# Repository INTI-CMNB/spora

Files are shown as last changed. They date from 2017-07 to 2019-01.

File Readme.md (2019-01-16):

SPORA PRE-RELEASE
==================

BUILD AWESOME WEARABLES

Open hardware platform for wearables.

Lots of sensors ready to use, program and expand at ease. All packed in an incredible small size.
More info at [Spora web page](https://sporaio.com/).

Final release in [Spora repo](https://github.com/sporaio).

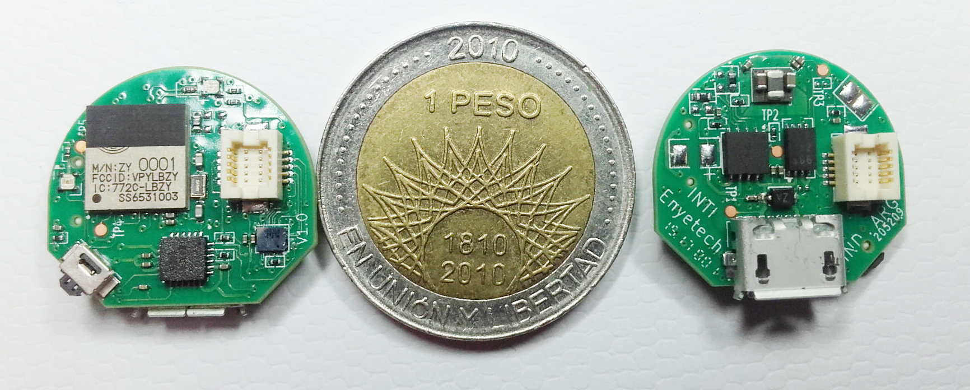
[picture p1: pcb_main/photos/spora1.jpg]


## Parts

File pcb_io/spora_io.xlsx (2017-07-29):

 |  |  |  |  |  |  | Board Qty: | 10
 |  |  |  |  |  |  | Total Cost: | $19.35 |  |  |  | $34.15 |  |  |  |  |  | $23.18 |  |  |  |  |  | $21.41 |  |  |  |  |  | $20.79 |  |  |  |  |  | $264.58
 |  |  |  |  |  |  | Unit Cost: | $1.93
Global Part Info |  |  |  |  |  |  |  |  | Digi-Key |  |  |  |  |  | Farnell |  |  |  |  |  | Mouser |  |  |  |  |  | Newark |  |  |  |  |  | Rs Components
Refs | Value | Desc | Footprint | Manf | Manf# | Qty | Unit$ | Ext$ | Avail | Purch | Unit$ | Ext$ | Cat# | Doc | Avail | Purch | Unit$ | Ext$ | Cat# | Doc | Avail | Purch | Unit$ | Ext$ | Cat# | Doc | Avail | Purch | Unit$ | Ext$ | Cat# | Doc | Avail | Purch | Unit$ | Ext$ | Cat# | Doc
J1 | DF12B 3.0 10DS 0.5V 81 | 10 Position Connector Receptacle, Center Strip Contacts Surface Mount Gold | footprints:df12(3.0)-10ds-0.5v | Hirose Electric Co Ltd | DF12B 3.0 -10DS- 0.5V 86 | 10 | $0.62 | $6.19 |  |  | $0.77 | $7.74 | H11719CT-ND | Link (http://www.digikey.com/scripts/DkSearch/dksus.dll?WT.z_header=search_go&lang=en) |  |  |  |  |  |  | 155 |  | $0.62 | $6.19 | 798-DF12B3010DS05V86 | Link (http://www.mouser.com/Search/Refine.aspx?Keyword=DF12B%203.0%20-10DS-%200.5V%2086%20)
C1,C2,C5-C8 | 1uF | CAP CER 1UF 16V X5R 0402 | footprints:c_0402 | Taiyo Yuden | EMK105BJ105KV-F | 60 | $0.03 | $1.75 | 602469 |  | $0.06 | $3.66 | 587-2477-1-ND | Link (http://www.digikey.com/scripts/DkSearch/dksus.dll?WT.z_header=search_go&lang=en) | 9184 |  | $0.03 | $1.75 | 2113064 | Link (http://it.farnell.com/taiyo-yuden/emk105bj105kv-f/condensatore-mlcc-x5r-1uf-16v/dp/2113064) | 58536 |  | $0.06 | $3.60 | 963-EMK105BJ105KV-F | Link (http://www.mouser.com/Search/Refine.aspx?Keyword=EMK105BJ105KV-F%20%20) |  |  | $0.19 | $11.40 | 84R9108 | Link (http://www.newark.com/taiyo-yuden/emk105bj105kv-f/ceramic-capacitor-1uf-16v-x5r/dp/84R9108)
G1 | LOGO_INTI | Logo INTI | footprints:LOGO_INTI |  |  | 10 | $0.00 | $0.00
CON2 | CON2 | Pad coneccion para tension de alimentacion del display | footprints:GS2 |  |  | 10 | $0.00 | $0.00
CON1 | CON6 | Conector para las lineas de SPI | footprints:CON_SPI_SMD |  |  | 10 | $0.00 | $0.00
J2 | ER-OLED0.49-1Series | Display OLED 0.49 | footprints:ER-OLED0.49-1_B |  |  | 10 | $0.00 | $0.00
C4 | 4.7uF | CAP CER 4.7UF 10V X5R 0402 | footprints:c_0402 | Samsung Electro-Mechanics America, Inc. | CL05A475MP5NRNC | 10 | $0.21 | $2.14 | 580535 |  | $0.21 | $2.14 | 1276-1482-1-ND | Link (http://www.digikey.com/scripts/DkSearch/dksus.dll?WT.z_header=search_go&lang=en) |  |  |  |  |  |  |  |  |  |  | Not Assigned | Link (http://www.mouser.com/Search/Refine.aspx?Keyword=CL05A475MP5NRNC%20)
C3 | 2.2uF | CAP CER 2.2UF 10V X5R 0402 | footprints:c_0402 | Murata Electronics North America | GRM155R61A225KE95D | 10 | $0.02 | $0.21 | 515443 |  | $0.07 | $0.66 | 490-10451-1-ND | Link (http://www.digikey.com/scripts/DkSearch/dksus.dll?WT.z_header=search_go&lang=en) | 18288 |  | $0.03 | $0.31 | 2456102 | Link (http://it.farnell.com/murata/grm155r61a225ke95d/condensatore-mlcc-x5r-2-2uf-10v/dp/2456102) | 263995 |  | $0.06 | $0.60 | 81-GRM155R61A225KE5D | Link (http://www.mouser.com/ProductDetail/Murata-Electronics/GRM155R61A225KE95D/) | 40000 |  | $0.02 | $0.21 | 03AC2565 | Link (http://www.newark.com/murata/grm155r61a225ke95d/capacitor-mlcc-x5r-2-2uf-10v-0402/dp/03AC2565)
R1 | 390K | RES SMD 390K OHM 1/16W 0402 | footprints:r_0402 | Yageo | RC0402JR-07390KL | 10 | $0.002 | $0.02 | 98703 |  | $0.01 | $0.12 | 311-390KJRCT-ND | Link (http://www.digikey.com/scripts/DkSearch/dksus.dll?WT.z_header=search_go&lang=en) |  |  |  |  | 9233075 | Link (http://it.farnell.com/webapp/wcs/stores/servlet/Search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) | 18070 |  | $0.01 | $0.08 | 603-RC0402JR-07390KL | Link (http://www.mouser.com/Search/Refine.aspx?Keyword=RC0402JR-07390KL%20%20Yageo) |  |  | $0.002 | $0.02 | 68R0007 | Link (http://www.newark.com/webapp/wcs/stores/servlet/Search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)
R5-R8 | 0 ohm | RES SMD 0.0OHM JUMPER 1/16W 0402 | footprints:r_0402 | Yageo | RC0402JR-070RL | 40 | $0.01 | $0.27 | 12655472 |  | $0.01 | $0.27 | 311-0.0JRCT-ND | Link (http://www.digikey.com/scripts/DkSearch/dksus.dll?WT.z_header=search_go&lang=en) | 185914 |  | $0.01 | $0.28 | 9232516 | Link (http://it.farnell.com/yageo-phycomp/rc0402jr-070rl/res-film-spesso-0r-5-0-0625w-0402/dp/9232516) | 1644687 |  | $0.01 | $0.32 | 603-RC0402JR-070RL | Link (http://www.mouser.com/Search/Refine.aspx?Keyword=RC0402JR-070RL%20Yageo) | 10896 |  | $0.01 | $0.28 | 67R9963 | Link (http://www.newark.com/yageo/rc0402jr-070rl/res-thick-film-0r-0-0625w-0402/dp/67R9963) | 2 |  | $4.71 | $188.36 | 618-5804 | Link (http://it.rs-online.com/web/c/?searchTerm=RC0402JR-070RL%20Yageo)
R4 | 0 ohm | RES SMD 0.0OHM JUMPER 1/16W 0402 | footprints:r_0402 | Yageo | RC0402JR-070RL | 10 | $0.01 | $0.07 | 12655472 |  | $0.01 | $0.10 | 311-0.0JRCT-ND | Link (http://www.digikey.com/scripts/DkSearch/dksus.dll?WT.z_header=search_go&lang=en) | 185914 |  | $0.01 | $0.07 | 9232516 | Link (http://it.farnell.com/yageo-phycomp/rc0402jr-070rl/res-film-spesso-0r-5-0-0625w-0402/dp/9232516) | 1644687 |  | $0.01 | $0.08 | 603-RC0402JR-070RL | Link (http://www.mouser.com/Search/Refine.aspx?Keyword=RC0402JR-070RL%20%20Yageo) | 10896 |  | $0.01 | $0.10 | 67R9963 | Link (http://www.newark.com/yageo/rc0402jr-070rl/res-thick-film-0r-0-0625w-0402/dp/67R9963) | 2 |  | $4.71 | $47.09 | 618-5804 | Link (http://it.rs-online.com/web/c/?searchTerm=RC0402JR-070RL%20%20Yageo)
R2,R3 | 10K | RES SMD 10K OHM 1/16W 0402 | footprints:r_0402 | Yageo | RC0402JR-0710KL | 20 | $0.01 | $0.11 | 3732168 |  | $0.01 | $0.24 | 311-10KJRCT-ND | Link (http://www.digikey.com/scripts/DkSearch/dksus.dll?WT.z_header=search_go&lang=en) | 112344 |  | $0.01 | $0.11 | 9232885 | Link (http://it.farnell.com/yageo-phycomp/rc0402jr-0710kl/res-film-spesso-10k-5-0-0625w/dp/9232885) | 307085 |  | $0.01 | $0.16 | 603-RC0402JR-0710KL | Link (http://www.mouser.com/Search/Refine.aspx?Keyword=RC0402JR-0710KL%20Yageo) | 44886 |  | $0.01 | $0.20 | 67R9964 | Link (http://www.newark.com/yageo/rc0402jr-0710kl/res-thick-film-10k-5-0-0625w-0402/dp/67R9964)
SW1,SW2 | SW_PUSH | SWITCH TACTILE SPST-NO 0.05A 12V | footprints:B3U_3000PB | Omron Electronics Inc-EMC Div | B3U-3000P-B | 20 | $0.43 | $8.58 | 17298 |  | $0.96 | $19.22 | SW1256CT-ND | Link (http://www.digikey.com/product-detail/en/omron-electronics-inc-emc-div/B3U-3000P-B/SW1256CT-ND/2748498) | 2004 |  | $1.03 | $20.66 | 1333656 | Link (http://it.farnell.com/omron-electronic-components/b3u-3000p-b/tactile-switch-side-actuated-smd/dp/1333656) | 557 |  | $0.52 | $10.38 | 653-B3U-3000P-B | Link (http://www.mouser.com/Search/Refine.aspx?Keyword=B3U-3000P-B%20%20) | 4000 |  | $0.43 | $8.58 | 39M4624 | Link (http://www.newark.com/omron-electronic-components/b3u-3000p-b/switch-tactile-spst-no-50ma-smd/dp/39M4624) |  |  | $1.46 | $29.13 | 807-4321 | Link (http://it.rs-online.com/web/c/?searchTerm=B3U-3000P-B%20%20)

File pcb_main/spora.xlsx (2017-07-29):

 |  |  |  |  |  |  | Board Qty: | 100
 |  |  |  |  |  |  | Total Cost: | $0.00 |  |  |  | $0.00 |  |  |  |  |  | $0.00 |  |  |  |  |  | $0.00 |  |  |  |  |  | $0.00 |  |  |  |  |  | $0.00
 |  |  |  |  |  |  | Unit Cost: | $0.00
Global Part Info |  |  |  |  |  |  |  |  | Digi-Key |  |  |  |  |  | Farnell |  |  |  |  |  | Mouser |  |  |  |  |  | Newark |  |  |  |  |  | Rs Components
Refs | Value | Desc | Footprint | Manf | Manf# | Qty | Unit$ | Ext$ | Avail | Purch | Unit$ | Ext$ | Cat# | Doc | Avail | Purch | Unit$ | Ext$ | Cat# | Doc | Avail | Purch | Unit$ | Ext$ | Cat# | Doc | Avail | Purch | Unit$ | Ext$ | Cat# | Doc | Avail | Purch | Unit$ | Ext$ | Cat# | Doc
G2 | LOGO_INTI |  |  |  |  | 0 | $0.00 | $0.00
U1 | TPS2115a | IC OR CTRLR SRC SELECT 8SON | footprints:TPS2115A | Texas Instruments | TPS2115ADRBR | 0 | $0.00 | $0.00 | 15291 |  | $0.00 | $0.00 | 296-23394-1-ND | Link (http://www.digikey.com/scripts/DkSearch/dksus.dll?WT.z_header=search_go&lang=en) | 252 |  | $0.00 | $0.00 | 2383157 | Link (http://it.farnell.com/webapp/wcs/stores/servlet/Search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) | 8544 |  | $0.00 | $0.00 | 595-TPS2115ADRBR | Link (http://www.mouser.com/ProductDetail/Texas-Instruments/TPS2115ADRBR/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) | 1806 |  | $0.00 | $0.00 | 87W8974 | Link (http://www.newark.com/texas-instruments/tps2115adrbr/power-load-switch-high-side-5/dp/87W8974)
F1-F6 | CONN_1 |  | footprints:FIDUCIAL_65MIL |  |  | 0 | $0.00 | $0.00
R15,R18 | 0 ohm | RES SMD 0.0OHM JUMPER 1/16W 0402 | footprints:r_0402 | Yageo | RC0402JR-070RL | 0 | $0.00 | $0.00 | 11253159 |  | $0.00 | $0.00 | 311-0.0JRCT-ND | Link (http://www.digikey.com/scripts/DkSearch/dksus.dll?WT.z_header=search_go&lang=en) | 117130 |  | $0.00 | $0.00 | 9232516 | Link (http://it.farnell.com/yageo-phycomp/rc0402jr-070rl/res-film-spesso-0r-5-0-0625w-0402/dp/9232516) | 1328355 |  | $0.00 | $0.00 | 603-RC0402JR-070RL | Link (http://www.mouser.com/Search/Refine.aspx?Keyword=RC0402JR-070RL%20Yageo) | 10000 |  | $0.00 | $0.00 | 67R9963 | Link (http://www.newark.com/yageo/rc0402jr-070rl/res-thick-film-0r-0-0625w-0402/dp/67R9963) | 25 |  | $0.00 | $0.00 | 618-5804 | Link (http://it.rs-online.com/web/c/?searchTerm=RC0402JR-070RL%20Yageo)
R2 | 68K | RES SMD 68K OHM 1 1/20W 0201 | footprints:r_0201 | Panasonic Electronic Components | ERJ-1GEF6802C | 0 | $0.00 | $0.00 | 842774 |  | $0.00 | $0.00 | P68.0KABCT-ND | Link (http://www.digikey.com/scripts/DkSearch/dksus.dll?WT.z_header=search_go&lang=en) |  |  |  |  |  |  | 7935 |  | $0.00 | $0.00 | 667-ERJ-1GEF6802C | Link (http://www.mouser.com/Search/Refine.aspx?Keyword=ERJ-1GEF6802C%20) |  |  | $0.00 | $0.00 | 51W4920 | Link (http://www.newark.com/webapp/wcs/stores/servlet/Search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)
R4 | 1.5K | RES SMD 1.5K OHM 5% 1/20W 0201 | footprints:r_0201 | Yageo | RC0201JR-071K5L | 0 | $0.00 | $0.00 | 35447 |  | $0.00 | $0.00 | 311-1.5KNCT-ND | Link (http://www.digikey.com/scripts/DkSearch/dksus.dll?WT.z_header=search_go&lang=en) |  |  |  |  |  |  |  |  | $0.00 | $0.00 | 603-RC0201JR-071K5L | Link (http://www.mouser.com/Search/Refine.aspx?Keyword=RC0201JR-071K5L%20%20Yageo) |  |  | $0.00 | $0.00 | 66R0918 | Link (http://www.newark.com/webapp/wcs/stores/servlet/Search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)
U3 | MCP73831 | Charger IC Lithium-Ion/Polymer 8-DFN (2x3) | footprints:MCP73821 | Microchip Technology | MCP73831-2ACI/MC | 0 | $0.00 | $0.00 | 2586 |  | $0.00 | $0.00 | MCP73831-2ACI/MC-ND | Link (http://www.digikey.com/scripts/DkSearch/dksus.dll?WT.z_header=search_go&lang=en) | 542 |  | $0.00 | $0.00 | 2709764 | Link (http://it.farnell.com/webapp/wcs/stores/servlet/Search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) | 923 |  | $0.00 | $0.00 | 579-MCP73831-2ACI/MC | Link (http://www.mouser.com/ProductDetail/Microchip-Technology/MCP73831-2ACI-MC/) | 542 |  | $0.00 | $0.00 | 12AC9925 | Link (http://www.newark.com/webapp/wcs/stores/servlet/Search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) | 220 |  | $0.00 | $0.00 | 823-1035 | Link (http://it.rs-online.com/web/c/?searchTerm=MCP73831-2ACI%2FMC%20)
U5 | LBCA2HNZYZ-711 | RF TXRX MOD BLUETOOTH CHIP ANT | footprints:LBCA2A2HNZYZ-711 | Murata Electronics North America | LBCA2HNZYZ-711 | 0 | $0.00 | $0.00 | 2503 |  | $0.00 | $0.00 | 490-10561-1-ND | Link (http://www.digikey.com/scripts/DkSearch/dksus.dll?WT.z_header=search_go&lang=en) |  |  |  |  |  |  | 389 |  | $0.00 | $0.00 | 81-LBCA2HNZYZ-711 | Link (http://www.mouser.com/ProductDetail/Murata-Electronics/LBCA2HNZYZ-711/)
U4 | MKL03Z32CAF4R | ARM Cortex-M0+ Kinetis KL03 Microcontroller IC 32-Bit 48MHz 32KB (32K x 8) FLASH 20-WLCSP | footprints:MKL03Z32CAF4R | Freescale Semiconductor NXP | MKL03Z32CAF4R | 0 | $0.00 | $0.00 |  |  | $0.00 | $0.00 | MKL03Z32CAF4RTR-ND | Link (http://www.digikey.com/scripts/DkSearch/dksus.dll?WT.z_header=search_go&lang=en) |  |  | $0.00 | $0.00 | 2433441 | Link (http://it.farnell.com/nxp/mkl03z32caf4r/mcu-32bit-cortex-m0-48mhz-wlcsp/dp/2433441) | 26224 |  | $0.00 | $0.00 | 841-MKL03Z32CAF4R | Link (http://www.mouser.com/Search/Refine.aspx?Keyword=841-MKL03Z32CAF4R%20%20) |  |  | $0.00 | $0.00 | 45X4873 | Link (http://www.newark.com/webapp/wcs/stores/servlet/Search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)
J1 | DF12D-3.0-10DP-0.5V-81 | 10 Position Connector Header Surface Mount | footprints:df12(3.0)-10dp-0.5v | Hirose Electric Co Ltd | DF12D-3.0-10DP-0.5V-81 | 0 | $0.00 | $0.00 | 1940 |  | $0.00 | $0.00 | H11736CT-ND | Link (http://www.digikey.com/scripts/DkSearch/dksus.dll?WT.z_header=search_go&lang=en) |  |  |  |  | 2300329 | Link (http://it.farnell.com/webapp/wcs/stores/servlet/Search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) | 1723 |  | $0.00 | $0.00 | 798-DF12D3010DP05V81 | Link (http://www.mouser.com/Search/Refine.aspx?Keyword=DF12D-3.0-10DP-0.5V-81%20) |  |  |  |  |  |  | 465 |  | $0.00 | $0.00 | 772-6838 | Link (http://it.rs-online.com/web/c/?searchTerm=DF12D-3.0-10DP-0.5V-81%20)
C4-C7,C9,C11,C12,C15 | 0.1uF | 0.10uF 10V Ceramic Capacitor X5R 0201 | footprints:c_0201 | Murata Electronics North America | GRM033R61A104ME15D | 0 | $0.00 | $0.00 | 1523359 |  | $0.00 | $0.00 | 490-5405-1-ND | Link (http://www.digikey.com/scripts/DkSearch/dksus.dll?WT.z_header=search_go&lang=en) |  |  |  |  |  |  | 478365 |  | $0.00 | $0.00 | 81-GRM033R61A104ME5D | Link (http://www.mouser.com/ProductDetail/Murata-Electronics/GRM033R61A104ME15D/) | 70021 |  | $0.00 | $0.00 | 04X3188 | Link (http://www.newark.com/webapp/wcs/stores/servlet/Search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)
R14 | 0 ohm | RES SMD 0.0OHM JUMPER 1/16W 0402 | footprints:r_0402 | Yageo | RC0402JR-070RL | 0 | $0.00 | $0.00 | 11253159 |  | $0.00 | $0.00 | 311-0.0JRCT-ND | Link (http://www.digikey.com/product-detail/en/yageo/RC0402JR-070RL/311-0.0JRCT-ND/729353) | 117130 |  | $0.00 | $0.00 | 9232516 | Link (http://it.farnell.com/yageo-phycomp/rc0402jr-070rl/res-film-spesso-0r-5-0-0625w-0402/dp/9232516) | 1328355 |  | $0.00 | $0.00 | 603-RC0402JR-070RL | Link (http://www.mouser.com/Search/Refine.aspx?Keyword=RC0402JR-070RL%20Yageo) | 10000 |  | $0.00 | $0.00 | 67R9963 | Link (http://www.newark.com/yageo/rc0402jr-070rl/res-thick-film-0r-0-0625w-0402/dp/67R9963) | 25 |  | $0.00 | $0.00 | 618-5804 | Link (http://it.rs-online.com/web/c/?searchTerm=RC0402JR-070RL%20Yageo)
BT1 | DNP | Pad's battery. | footprints:BAT_CON |  |  | 0 | $0.00 | $0.00
Y1 | 32,768 kHz | CRYSTAL 32.7680KHZ 9PF SMD | footprints:ABS05-32.768KHZ-9-T | Abracon LLC | ABS05-32.768KHZ-9-T | 0 | $0.00 | $0.00 |  |  | $0.00 | $0.00 | 535-11897-1-ND | Link (http://www.digikey.com/scripts/DkSearch/dksus.dll?WT.z_header=search_go&lang=en) | 8725 |  | $0.00 | $0.00 | 2467858 | Link (http://it.farnell.com/abracon/abs05-32-768khz-9-t/crystal-32-768khz-9pf-1-6-x-1mm/dp/2467858) | 8984 |  | $0.00 | $0.00 | 815-ABS05-32.768K9T | Link (http://www.mouser.com/Search/Refine.aspx?Keyword=ABS05-32.768KHZ-9-T%20) | 7710 |  | $0.00 | $0.00 | 40Y2049 | Link (http://www.newark.com/abracon/abs05-32-768khz-9-t/crystal-32-768khz-9pf-1-6-x-1mm/dp/40Y2049)
TP1-TP5 | TESTPOINT |  | footprints:TESTPOINT |  |  | 0 | $0.00 | $0.00
C16,C17 | 0.1uF | 0.10uF 10V Ceramic Capacitor X5R 0201 | footprints:c_0201 | Murata Electronics North America | GRM033R61A104ME15D | 0 | $0.00 | $0.00 | 1523359 |  | $0.00 | $0.00 | 490-5405-1-ND | Link (http://www.digikey.com/scripts/DkSearch/dksus.dll?WT.z_header=search_go&lang=en) |  |  |  |  |  |  | 478365 |  | $0.00 | $0.00 | 81-GRM033R61A104ME5D | Link (http://www.mouser.com/ProductDetail/Murata-Electronics/GRM033R61A104ME15D/) | 70021 |  | $0.00 | $0.00 | 04X3188 | Link (http://www.newark.com/webapp/wcs/stores/servlet/Search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)
C13 | 2.2uF | 2.2uF 6.3V Ceramic Capacitor X5R 0201 | footprints:c_0201 | Murata Electronics North America | GRM033R60J225ME15D | 0 | $0.00 | $0.00 | 197313 |  | $0.00 | $0.00 | 490-13224-1-ND | Link (http://www.digikey.com/scripts/DkSearch/dksus.dll?WT.z_header=search_go&lang=en) |  |  |  |  |  |  |  |  | $0.00 | $0.00 | 81-GRM033R60J225ME5D | Link (http://www.mouser.com/Search/Refine.aspx?Keyword=GRM033R60J225ME15D%20)
R12,R13 | 220 | RES SMD 220 OHM 5 1/20W 0201 | footprints:r_0201 | Yageo | RC0201JR-07220RL | 0 | $0.00 | $0.00 | 9118 |  | $0.00 | $0.00 | 311-220NCT-ND | Link (http://www.digikey.com/scripts/DkSearch/dksus.dll?WT.z_header=search_go&lang=en) | 20411 |  | $0.00 | $0.00 | 1711597 | Link (http://it.farnell.com/multicomp/mcre000124/res-film-spesso-220r-1-0-05w-0201/dp/1711597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) | 7542 |  | $0.00 | $0.00 | 603-RC0201JR-07220RL | Link (http://www.mouser.com/Search/Refine.aspx?Keyword=RC0201JR-07220RL%20Yageo) |  |  | $0.00 | $0.00 | 66R0974 | Link (http://www.newark.com/webapp/wcs/stores/servlet/Search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)
C14 | 10nF | 10000pF 10V Ceramic Capacitor X5R 0201 | footprints:c_0201 | Murata Electronics North America | GRM033R61A103KA01D | 0 | $0.00 | $0.00 | 1316338 |  | $0.00 | $0.00 | 490-3166-1-ND | Link (http://www.digikey.com/scripts/DkSearch/dksus.dll?WT.z_header=search_go&lang=en) | 22943 |  | $0.00 | $0.00 | 2470449 | Link (http://it.farnell.com/murata/grm033r61a103ka01d/condensat-mlcc-x5r-0-01uf-10v/dp/2470449) | 267126 |  | $0.00 | $0.00 | 81-GRM033R61A103KA01 | Link (http://www.mouser.com/Search/Refine.aspx?Keyword=GRM033R61A103KA01D%20) | 21543 |  | $0.00 | $0.00 | 45Y5192 | Link (http://www.newark.com/murata/grm033r61a103ka01d/multilayer-ceramic-capacitor-grm/dp/45Y5192) | 14500 |  | $0.00 | $0.00 | 820-0659 | Link (http://it.rs-online.com/web/c/?searchTerm=GRM033R61A103KA01D%20)
C8,C10 | 1uF | 1uF 10V Ceramic Capacitor X5R 0201 | footprints:c_0201 | Samsung Electro-Mechanics America, Inc. | CL03A105MP3ZSNH | 0 | $0.00 | $0.00 |  |  | $0.00 | $0.00 | 1276-6816-1-ND | Link (http://www.digikey.com/scripts/DkSearch/dksus.dll?WT.z_header=search_go&lang=en)
D1 | ESD5V0D3-TP | TVS DIODE 5VWM 9.8VC SOD323 | footprints:SOD-323 | Micro Commercial Co | ESD5V0D3-TP | 0 | $0.00 | $0.00 | 29883 |  | $0.00 | $0.00 | ESD5V0D3-TPMSCT-ND | Link (http://www.digikey.com/scripts/DkSearch/dksus.dll?WT.z_header=search_go&lang=en) | 2622 |  | $0.00 | $0.00 | 1924352 | Link (http://it.farnell.com/webapp/wcs/stores/servlet/Search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) | 662 |  | $0.00 | $0.00 | 833-ESD5V0D3-TP | Link (http://www.mouser.com/Search/Refine.aspx?Keyword=ESD5V0D3-TP%20) | 2622 |  | $0.00 | $0.00 | 51T4894 | Link (http://www.newark.com/micro-commercial-components/esd5v0d3-tp/esd-suppressor-200mw-15-5v-sod/dp/51T4894)
D2,D3 | LED_RABG | (RGB) LED Indication | footprints:SML-LX0404SIUPGUSB | Lumex Opto/Components Inc. | SML-LX0404SIUPGUSB | 0 | $0.00 | $0.00 | 183870 |  | $0.00 | $0.00 | 67-2125-1-ND | Link (http://www.digikey.com/scripts/DkSearch/dksus.dll?WT.z_header=search_go&lang=en) | 6000 |  | $0.00 | $0.00 | 2369058 | Link (http://it.farnell.com/lumex/sml-lx0404siupgusb/quasarbrite-0404-smd-rgb-led-full/dp/2369058) | 110125 |  | $0.00 | $0.00 | 696-LX0404SIUPGUSB | Link (http://www.mouser.com/Search/Refine.aspx?Keyword=SML-LX0404SIUPGUSB%20) | 2037 |  | $0.00 | $0.00 | 23T0583 | Link (http://www.newark.com/lumex/sml-lx0404siupgusb/quasarbrite-0404-smd-rgb-led/dp/23T0583) |  |  | $0.00 | $0.00 | 888-6013 | Link (http://it.rs-online.com/web/c/?searchTerm=SML-LX0404SIUPGUSB%20)
C19,C21 | DNP |  | footprints:c_0402 |  |  | 0 | $0.00 | $0.00
R16,R17 | DNP |  | footprints:r_0402 |  |  | 0 | $0.00 | $0.00
R3 | DNP | RES SMD 470 OHM 5 1/20W 0201 | footprints:r_0201 | Yageo | RC0201JR-07470RL | 0 | $0.00 | $0.00 | 58136 |  | $0.00 | $0.00 | 311-470NCT-ND | Link (http://www.digikey.com/scripts/DkSearch/dksus.dll?WT.z_header=search_go&lang=en) |  |  |  |  |  |  | 10269 |  | $0.00 | $0.00 | 603-RC0201JR-07470RL | Link (http://www.mouser.com/Search/Refine.aspx?Keyword=RC0201JR-07470RL%20Yageo)
C20 | 22pF | CAP CER 22PF 10V NP0 0402 | footprints:c_0402 | Wurth Electronics Inc | 885012005009 | 0 | $0.00 | $0.00 | 18319 |  | $0.00 | $0.00 | 732-7427-1-ND | Link (http://www.digikey.com/scripts/DkSearch/dksus.dll?WT.z_header=search_go&lang=en) |  |  | $0.00 | $0.00 | 2533782 | Link (http://it.farnell.com/wurth-elektronik/885012005009/condensatore-mlcc-np0-22pf-10v/dp/2533782) | 13417 |  | $0.00 | $0.00 | 710-885012005009 | Link (http://www.mouser.com/Search/Refine.aspx?Keyword=885012005009%20) |  |  | $0.00 | $0.00 | 15AC9271 | Link (http://www.newark.com/webapp/wcs/stores/servlet/Search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)
GS2 | Rest_MCU | Pad para poder reemplazar boton de reset | footprints:GS2 |  |  | 0 | $0.00 | $0.00
R6,R7,R9 | 10K | RES SMD 10K OHM 5% 1/20W 0201 | footprints:r_0201 | Yageo | RC0201JR-0710KL | 0 | $0.00 | $0.00 | 520924 |  | $0.00 | $0.00 | 311-10KNCT-ND | Link (http://www.digikey.com/scripts/DkSearch/dksus.dll?WT.z_header=search_go&lang=en) | 31390 |  | $0.00 | $0.00 | 1458865 | Link (http://it.farnell.com/yageo-phycomp/rc0201jr-0710kl/res-film-spesso-10k-5-0-05w-0201/dp/1458865) | 128861 |  | $0.00 | $0.00 | 603-RC0201JR-0710KL | Link (http://www.mouser.com/Search/Refine.aspx?Keyword=RC0201JR-0710KL%20Yageo) | 9556 |  | $0.00 | $0.00 | 67R9867 | Link (http://www.newark.com/yageo/rc0201jr-0710kl/res-thick-film-10k-5-0-5w-0201/dp/67R9867)
USB1 | USB-MICRO | USB - micro AB USB 2.0 Receptacle Connector 5 Position Surface Mount | footprints:conn_usb_B_micro_smd | Hirose Electric Co Ltd | ZX62-AB-5PA(31) | 0 | $0.00 | $0.00 | 2907 |  | $0.00 | $0.00 | H125279CT-ND | Link (http://www.digikey.com/scripts/DkSearch/dksus.dll?WT.z_header=search_go&lang=en) |  |  | $0.00 | $0.00 | 2663341 | Link (http://it.farnell.com/webapp/wcs/stores/servlet/Search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) |  |  | $0.00 | $0.00 | 798-ZX62-AB-5PA31 | Link (http://www.mouser.com/Search/Refine.aspx?Keyword=ZX62-AB-5PA%2831%29%20%20) |  |  |  |  |  |  |  |  |  |  | 685-0961 | Link (http://it.rs-online.com/web/p/connettori-micro-usb/6850961/)
C1-C3,C22 | 4.7uF | 4.7uF 6.3V Ceramic Capacitor X5R 0201 | footprints:c_0201 | Murata Electronics North America | GRM035R60J475ME15D | 0 | $0.00 | $0.00 | 2364 |  | $0.00 | $0.00 | 490-13230-1-ND | Link (http://www.digikey.com/scripts/DkSearch/dksus.dll?WT.z_header=search_go&lang=en) |  |  |  |  |  |  | 76837 |  | $0.00 | $0.00 | 81-GRM035R60J475ME5D | Link (http://www.mouser.com/Search/Refine.aspx?Keyword=GRM035R60J475ME15D%20)
R10,R19 | 330 | RES SMD 330 OHM 5% 1/20W 0201 | footprints:r_0201 | Yageo | RC0201JR-07330RL | 0 | $0.00 | $0.00 | 204492 |  | $0.00 | $0.00 | 311-330NCT-ND | Link (http://www.digikey.com/scripts/DkSearch/dksus.dll?WT.z_header=search_go&lang=en) |  |  |  |  |  |  | 42275 |  | $0.00 | $0.00 | 603-RC0201JR-07330RL | Link (http://www.mouser.com/Search/Refine.aspx?Keyword=RC0201JR-07330RL%20%20Yageo) |  |  | $0.00 | $0.00 | 66R0996 | Link (http://www.newark.com/webapp/wcs/stores/servlet/Search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)
C18 | 22pF | CAP CER 22PF 10V NP0 0402 | footprints:c_0402 | Wurth Electronics Inc | 885012005009 | 0 | $0.00 | $0.00 | 18319 |  | $0.00 | $0.00 | 732-7427-1-ND | Link (http://www.digikey.com/scripts/DkSearch/dksus.dll?WT.z_header=search_go&lang=en) |  |  | $0.00 | $0.00 | 2533782 | Link (http://it.farnell.com/wurth-elektronik/885012005009/condensatore-mlcc-np0-22pf-10v/dp/2533782) | 13417 |  | $0.00 | $0.00 | 710-885012005009 | Link (http://www.mouser.com/Search/Refine.aspx?Keyword=885012005009%20) |  |  | $0.00 | $0.00 | 15AC9271 | Link (http://www.newark.com/webapp/wcs/stores/servlet/Search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)
SW1 | SIDE_SW | Tactile Switch SPST-NO Side Actuated Surface Mount | footprints:B3U_3000PB | Omron Electronics Inc-EMC Div | B3U-3000P-B | 0 | $0.00 | $0.00 | 1253 |  | $0.00 | $0.00 | SW1256CT-ND | Link (http://www.digikey.com/product-detail/en/omron-electronics-inc-emc-div/B3U-3000P-B/SW1256CT-ND/2748498) | 1879 |  | $0.00 | $0.00 | 1333656 | Link (http://it.farnell.com/omron-electronic-components/b3u-3000p-b/tactile-switch-side-actuated-smd/dp/1333656) | 3757 |  | $0.00 | $0.00 | 653-B3U-3000P-B | Link (http://www.mouser.com/Search/Refine.aspx?Keyword=B3U-3000P-B%20) | 4000 |  | $0.00 | $0.00 | 39M4624 | Link (http://www.newark.com/omron-electronic-components/b3u-3000p-b/switch-tactile-spst-no-50ma-smd/dp/39M4624) |  |  | $0.00 | $0.00 | 807-4321 | Link (http://it.rs-online.com/web/c/?searchTerm=B3U-3000P-B%20)
R1 | 49.9 | RES SMD 49.9 OHM 1 1/20W 0201 | footprints:r_0201 | Panasonic Electronic Components | ERJ-1GEF49R9C | 0 | $0.00 | $0.00 | 1050905 |  | $0.00 | $0.00 | P49.9ABCT-ND | Link (http://www.digikey.com/product-detail/en/panasonic-electronic-components/ERJ-1GEF49R9C/P49.9ABCT-ND/1467356) | 16011 |  | $0.00 | $0.00 | 2282167 | Link (http://it.farnell.com/webapp/wcs/stores/servlet/Search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) | 20427 |  | $0.00 | $0.00 | 667-ERJ-1GEF49R9C | Link (http://www.mouser.com/Search/Refine.aspx?Keyword=ERJ-1GEF49R9C%20) | 16011 |  | $0.00 | $0.00 | 53W4021 | Link (http://www.newark.com/panasonic-electronic-components/erj-1gef49r9c/res-thick-film-49r9-1-0-05w-0201/dp/53W4021) |  |  | $0.00 | $0.00 | 812-6602 | Link (http://it.rs-online.com/web/c/?searchTerm=ERJ-1GEF49R9C%20)
G1 | LOGO_INTI |  | footprints:LOGO_INTI |  |  | 0 | $0.00 | $0.00
U6 | MPU-9250 | Accelerometer, Gyroscope, Magnetometer, 3 Axis Sensor I2C, SPI Output | footprints:MPU-9250 | InvenSense | MPU-9250 | 0 | $0.00 | $0.00 | 41787 |  | $0.00 | $0.00 | 1428-1019-1-ND | Link (http://www.digikey.com/scripts/DkSearch/dksus.dll?WT.z_header=search_go&lang=en) |  |  |  |  |  |  | 20 |  | $0.00 | $0.00 | 474-SEN-14001 | Link (http://www.mouser.com/ProductDetail/SparkFun/SEN-14001/) |  |  |  |  |  |  | 10 |  | $0.00 | $0.00 | 883-7942 | Link (http://it.rs-online.com/web/c/?searchTerm=MPU-9250%20)
R5,R8 | 4.7K | RES SMD 4.7K OHM 5% 1/20W 0201 | footprints:r_0201 | Yageo | RC0201JR-074K7L | 0 | $0.00 | $0.00 | 450839 |  | $0.00 | $0.00 | 311-4.7KNCT-ND | Link (http://www.digikey.com/scripts/DkSearch/dksus.dll?WT.z_header=search_go&lang=en) | 31320 |  | $0.00 | $0.00 | 1458886 | Link (http://it.farnell.com/yageo-phycomp/rc0201jr-074k7l/res-film-spesso-4k7-5-0-05w-0201/dp/1458886) | 74532 |  | $0.00 | $0.00 | 603-RC0201JR-074K7L | Link (http://www.mouser.com/Search/Refine.aspx?Keyword=RC0201JR-074K7L%20Yageo) | 31280 |  | $0.00 | $0.00 | 59M5086 | Link (http://www.newark.com/webapp/wcs/stores/servlet/Search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)
U2 | TPS82740B | DC DC Converter 1 Output 2.6 - 3.3 V 200mA 2.2V - 5.5V Input | footprints:TPS82740B | Texas Instruments | TPS82740BSIPT | 0 | $0.00 | $0.00 | 2985 |  | $0.00 | $0.00 | 296-37973-1-ND | Link (http://www.digikey.com/scripts/DkSearch/dksus.dll?WT.z_header=search_go&lang=en) | 144 |  | $0.00 | $0.00 | 2434676 | Link (http://it.farnell.com/webapp/wcs/stores/servlet/Search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) | 959 |  | $0.00 | $0.00 | 595-TPS82740BSIPT | Link (http://www.mouser.com/ProductDetail/Texas-Instruments/TPS82740BSIPT/) | 144 |  | $0.00 | $0.00 | 79X2094 | Link (http://www.newark.com/webapp/wcs/stores/servlet/Search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)
J2 | DF12D-3.0-10DP-0.5V-81 | 10 Position Connector Header Surface Mount | footprints:df12(3.0)-10dp-0.5v | Hirose Electric Co Ltd | DF12D-3.0-10DP-0.5V-81 | 0 | $0.00 | $0.00 | 1940 |  | $0.00 | $0.00 | H11736CT-ND | Link (http://www.digikey.com/scripts/DkSearch/dksus.dll?WT.z_header=search_go&lang=en) |  |  |  |  | 2300329 | Link (http://it.farnell.com/webapp/wcs/stores/servlet/Search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) | 1723 |  | $0.00 | $0.00 | 798-DF12D3010DP05V81 | Link (http://www.mouser.com/Search/Refine.aspx?Keyword=DF12D-3.0-10DP-0.5V-81%20) |  |  |  |  |  |  | 465 |  | $0.00 | $0.00 | 772-6838 | Link (http://it.rs-online.com/web/c/?searchTerm=DF12D-3.0-10DP-0.5V-81%20)

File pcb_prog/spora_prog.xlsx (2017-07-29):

 |  |  |  |  |  |  | Board Qty: | 4
 |  |  |  |  |  |  | Total Cost: | $27.01 |  |  |  | $43.37 |  |  |  |  |  | $16.47 |  |  |  |  |  | $32.10 |  |  |  |  |  | $18.44 |  |  |  |  |  | $345.84
 |  |  |  |  |  |  | Unit Cost: | $6.75
Global Part Info |  |  |  |  |  |  |  |  | Digi-Key |  |  |  |  |  | Farnell |  |  |  |  |  | Mouser |  |  |  |  |  | Newark |  |  |  |  |  | Rs Components
Refs | Value | Desc | Footprint | Manf | Manf# | Qty | Unit$ | Ext$ | Avail | Purch | Unit$ | Ext$ | Cat# | Doc | Avail | Purch | Unit$ | Ext$ | Cat# | Doc | Avail | Purch | Unit$ | Ext$ | Cat# | Doc | Avail | Purch | Unit$ | Ext$ | Cat# | Doc | Avail | Purch | Unit$ | Ext$ | Cat# | Doc
C2,C4-C6 | 10uF | 10uF 10% 16V Ceramic Capacitor X5R 0805 | footprints:c_0805 | Murata Electronics North America | GRM21BR61C106KE15K | 16 | $0.06 | $0.95 | 325564 |  | $0.14 | $2.32 | 490-6473-1-ND | Link (http://www.digikey.com/scripts/DkSearch/dksus.dll?WT.z_header=search_go&lang=en) | 3088 |  | $0.07 | $1.09 | 2611940 | Link (http://it.farnell.com/murata/grm21br61c106ke15k/cond-mlcc-x5r-10uf-16v-0805/dp/2611940) |  |  | $0.13 | $2.08 | 81-GRM21BR61C106KE5K | Link (http://www.mouser.com/Search/Refine.aspx?Keyword=GRM21BR61C106KE15K%20) | 14040 |  | $0.13 | $2.08 | 96Y9274 | Link (http://www.newark.com/webapp/wcs/stores/servlet/Search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) | 1700 |  | $0.06 | $0.95 | 820-2762 | Link (http://it.rs-online.com/web/c/?searchTerm=GRM21BR61C106KE15K%20)
U2 | LM1117 | Linear Voltage Regulator IC Positive Adjustable 1 Output 1.25 V 13.8 V 800mA SOT-223 | footprints:sot223 | Texas Instruments | LM1117MPX-ADJ/NOPB | 4 | $0.43 | $1.73 | 16788 |  | $1.04 | $4.16 | LM1117MPX-ADJ/NOPBCT-ND | Link (http://www.digikey.com/scripts/DkSearch/dksus.dll?WT.z_header=search_go&lang=en) | 4000 |  | $0.43 | $1.73 | 2435821 | Link (http://it.farnell.com/texas-instruments/lm1117mpx-adj-nopb/ic-reg-linear-0-8a-15v-sot223/dp/2435821) |  |  |  |  |  |  | 2175 |  | $1.00 | $4.00 | 86W6750 | Link (http://www.newark.com/texas-instruments/lm1117mpx-adj-nopb/voltage-regulator-adjustable-1/dp/86W6750)
C1 | 10uF | 10uF 10% 16V Ceramic Capacitor X5R 0805 | footprints:c_0805 | Murata Electronics North America | GRM21BR61C106KE15K | 4 | $0.06 | $0.24 | 325564 |  | $0.20 | $0.80 | 490-6473-1-ND | Link (http://www.digikey.com/scripts/DkSearch/dksus.dll?WT.z_header=search_go&lang=en) | 3088 |  | $0.07 | $0.27 | 2611940 | Link (http://it.farnell.com/murata/grm21br61c106ke15k/cond-mlcc-x5r-10uf-16v-0805/dp/2611940) |  |  | $0.19 | $0.76 | 81-GRM21BR61C106KE5K | Link (http://www.mouser.com/Search/Refine.aspx?Keyword=GRM21BR61C106KE15K%20) | 14040 |  | $0.13 | $0.52 | 96Y9274 | Link (http://www.newark.com/webapp/wcs/stores/servlet/Search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) | 1700 |  | $0.06 | $0.24 | 820-2762 | Link (http://it.rs-online.com/web/c/?searchTerm=GRM21BR61C106KE15K%20)
CON1 | BARREL_JACK | Power Barrel Connector Jack 0.70mm ID (0.028), 2.35mm OD (0.093) EIAJ-1 Surface Mount, Right Angle | footprints:Pj-38-smt | CUI Inc. | PJ-038-SMT-TR | 4 | $1.19 | $4.76 | 949 |  | $1.32 | $5.28 | CP-038PJCT-ND | Link (http://www.digikey.com/scripts/DkSearch/dksus.dll?WT.z_header=search_go&lang=en) |  |  |  |  |  |  | 2822 |  | $1.19 | $4.76 | 490-PJ-038-SMT-TR | Link (http://www.mouser.com/Search/Refine.aspx?Keyword=PJ-038-SMT-TR%20)
C8-C11 | 0.1uF | CAP CER 0.1UF 16V X7R 0805 | footprints:c_0805 | Murata Electronics North America | GRM219R71C104KA01D | 16 | $0.02 | $0.37 | 245486 |  | $0.10 | $1.57 | 490-1683-1-ND | Link (http://www.digikey.com/scripts/DkSearch/dksus.dll?WT.z_header=search_go&lang=en) | 1347 |  | $0.05 | $0.78 | 2611934 | Link (http://it.farnell.com/murata/grm219r71c104ka01d/cond-mlcc-x7r-0-1uf-16v-0805/dp/2611934) | 43791 |  | $0.05 | $0.82 | 81-GRM40X104K16D | Link (http://www.mouser.com/Search/Refine.aspx?Keyword=GRM219R71C104KA01D%20%20) | 1302 |  | $0.05 | $0.82 | 96Y9285 | Link (http://www.newark.com/webapp/wcs/stores/servlet/Search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) | 500 |  | $0.02 | $0.37 | 790-0667 | Link (http://it.rs-online.com/web/c/?searchTerm=GRM219R71C104KA01D%20%20)
CON4 | SWD_MCU | 10 Positions Header, Unshrouded Connector 0.100 (2.54mm) Through Hole Tin | Pin_Headers:Pin_Header_Straight_2x05 | Amphenol FCI | 67997-410HLF | 4 | $0.25 | $0.99 | 76841 |  | $0.26 | $1.04 | 609-3243-ND | Link (http://www.digikey.com/scripts/DkSearch/dksus.dll?WT.z_header=search_go&lang=en) |  |  | $0.25 | $0.99 | 2751378 | Link (http://it.farnell.com/amphenol-fci/67997-410hlf/connettore-basetta-10pos-2fil/dp/2751378) | 27635 |  | $0.25 | $1.00 | 649-67997-410HLF | Link (http://www.mouser.com/ProductDetail/Amphenol-FCI/67997-410HLF/) | 3333 |  | $0.25 | $1.01 | 33M7903 | Link (http://www.newark.com/webapp/wcs/stores/servlet/Search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) | 2 |  | $14.65 | $58.59 | 863-2835 | Link (http://it.rs-online.com/web/c/?searchTerm=67997-410HLF%20)
R2 | 470 | RES SMD 470 OHM 1% 1/8W 0805 | footprints:r_0805 | Yageo | RC0805FR-07470RL | 4 | $0.01 | $0.05 | 601074 |  | $0.10 | $0.40 | 311-470CRCT-ND | Link (http://www.digikey.com/scripts/DkSearch/dksus.dll?WT.z_header=search_go&lang=en) | 27957 |  | $0.01 | $0.05 | 9237445 | Link (http://it.farnell.com/yageo-phycomp/rc0805fr-07470rl/res-film-spesso-470r-1-0-125w/dp/9237445) | 78341 |  | $0.10 | $0.40 | 603-RC0805FR-07470RL | Link (http://www.mouser.com/ProductDetail/Yageo/RC0805FR-07470RL/?qs=sGAEpiMZZMu61qfTUdNhG2W3y6AnIMnkWKq1cojGCY0%3D) | 15556 |  | $0.02 | $0.09 | 89K7298 | Link (http://www.newark.com/yageo-phycomp/rc0805fr-07470rl/res-thick-film-470r-1-0-125w-0805/dp/89K7298) | 14 |  | $23.36 | $93.46 | 618-2546 | Link (http://it.rs-online.com/web/c/?searchTerm=RC0805FR-07470RL%20Yageo)
J1 | DF12B-3.0-10DS-0.5V-81 | 10 Position Connector Receptacle, Center Strip Contacts Surface Mount Gold | footprints:df12(3.0)-10ds-0.5v | Hirose Electric Co Ltd | DF12B3.0-10DS-0.5V86 | 4 | $0.83 | $3.32 | 968 |  | $0.83 | $3.32 | H11719CT-ND | Link (http://www.digikey.com/scripts/DkSearch/dksus.dll?WT.z_header=search_go&lang=en) |  |  |  |  |  |  | 155 |  | $0.83 | $3.32 | 798-DF12B3010DS05V86 | Link (http://www.mouser.com/Search/Refine.aspx?Keyword=DF12B3.0-10DS-0.5V86%20)
R4 | 280 | RES SMD 280 OHM 1% 1/8W 0805 | footprints:r_0805 | Yageo | RC0805FR-07280RL | 4 | $0.01 | $0.02 | 9616 |  | $0.10 | $0.40 | 311-280CRCT-ND | Link (http://www.digikey.com/scripts/DkSearch/dksus.dll?WT.z_header=search_go&lang=en) |  |  |  |  |  |  | 14601 |  | $0.10 | $0.40 | 603-RC0805FR-07280RL | Link (http://www.mouser.com/Search/Refine.aspx?Keyword=RC0805FR-07280RL%20%20Yageo) |  |  | $0.01 | $0.02 | 66R3150 | Link (http://www.newark.com/webapp/wcs/stores/servlet/Search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) | 3 |  | $23.36 | $93.46 | 618-3842 | Link (http://it.rs-online.com/web/c/?searchTerm=RC0805FR-07280RL%20%20)
R1 | 270 | RES SMD 270 OHM 1% 1/8W 0805 | footprints:r_0805 | Yageo | RC0805FR-07270RL | 4 | $0.01 | $0.05 | 92087 |  | $0.10 | $0.40 | 311-270CRCT-ND | Link (http://www.digikey.com/scripts/DkSearch/dksus.dll?WT.z_header=search_go&lang=en) | 34356 |  | $0.01 | $0.05 | 9237410 | Link (http://it.farnell.com/yageo-phycomp/rc0805fr-07270rl/res-film-spesso-270r-1-0-125w/dp/9237410) |  |  |  |  |  |  | 34676 |  | $0.02 | $0.08 | 26M6837 | Link (http://www.newark.com/yageo-phycomp/rc0805fr-07270rl/surface-mount-thick-film-resistor/dp/26M6837) | 8 |  | $9.96 | $39.84 | 618-4176 | Link (http://it.rs-online.com/web/c/?searchTerm=RC0805FR-07270RL%20Yageo)
CON3 | SWD_BT | 10 Positions Header, Unshrouded Connector 0.100 (2.54mm) Through Hole Tin | Pin_Headers:Pin_Header_Straight_2x05 | Amphenol FCI | 67997-410HLF | 4 | $0.25 | $0.99 | 76841 |  | $0.26 | $1.04 | 609-3243-ND | Link (http://www.digikey.com/scripts/DkSearch/dksus.dll?WT.z_header=search_go&lang=en) |  |  | $0.25 | $0.99 | 2751378 | Link (http://it.farnell.com/amphenol-fci/67997-410hlf/connettore-basetta-10pos-2fil/dp/2751378) | 27635 |  | $0.25 | $1.00 | 649-67997-410HLF | Link (http://www.mouser.com/ProductDetail/Amphenol-FCI/67997-410HLF/) | 3333 |  | $0.25 | $1.01 | 33M7903 | Link (http://www.newark.com/webapp/wcs/stores/servlet/Search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) | 2 |  | $14.65 | $58.59 | 863-2835 | Link (http://it.rs-online.com/web/c/?searchTerm=67997-410HLF%20)
SW1,SW2 | SIDE_SW | Tactile Switch SPST-NO Top Actuated Surface Mount | footprints:B3U_1000PB | Omron Electronics Inc-EMC Div | B3U-1000P-B | 8 | $0.43 | $3.43 | 8747 |  | $1.00 | $8.00 | SW1143CT-ND | Link (http://www.digikey.com/scripts/DkSearch/dksus.dll?WT.z_header=search_go&lang=en) | 4150 |  | $1.03 | $8.27 | 1333654 | Link (http://it.farnell.com/omron-electronic-components/b3u-1000p-b/switch-spst-no-0-05a-12v-smd-boss/dp/1333654) | 4011 |  | $1.03 | $8.24 | 653-B3U-1000P-B | Link (http://www.mouser.com/Search/Refine.aspx?Keyword=B3U-1000P-B%20) | 3500 |  | $0.43 | $3.43 | 39M4616 | Link (http://www.newark.com/webapp/wcs/stores/servlet/Search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)
U1 | LM1117 | Linear Voltage Regulator IC Positive Adjustable 1 Output 1.25 V 13.8 V 800mA SOT-223 | footprints:sot223 | Texas Instruments | LM1117MPX-ADJ/NOPB | 4 | $0.43 | $1.73 | 16788 |  | $1.04 | $4.16 | LM1117MPX-ADJ/NOPBCT-ND | Link (http://www.digikey.com/scripts/DkSearch/dksus.dll?WT.z_header=search_go&lang=en) | 4000 |  | $0.43 | $1.73 | 2435821 | Link (http://it.farnell.com/texas-instruments/lm1117mpx-adj-nopb/ic-reg-linear-0-8a-15v-sot223/dp/2435821) |  |  |  |  |  |  | 2175 |  | $1.00 | $4.00 | 86W6750 | Link (http://www.newark.com/texas-instruments/lm1117mpx-adj-nopb/voltage-regulator-adjustable-1/dp/86W6750)
R3 | 1,2k | RES SMD 1.2K OHM 1% 1/8W 0805 | footprints:r_0805 | Yageo | RC0805FR-071K2L | 4 | $0.01 | $0.05 | 292484 |  | $0.10 | $0.40 | 311-1.20KCRCT-ND | Link (http://www.digikey.com/scripts/DkSearch/dksus.dll?WT.z_header=search_go&lang=en) | 57862 |  | $0.01 | $0.05 | 9237500 | Link (http://it.farnell.com/yageo-phycomp/rc0805fr-071k2l/res-film-spesso-1k2-1-0-125w-0805/dp/9237500) | 60091 |  | $0.10 | $0.40 | 603-RC0805FR-071K2L | Link (http://www.mouser.com/ProductDetail/Yageo/RC0805FR-071K2L/?qs=sGAEpiMZZMu61qfTUdNhG5eFuApKbqVdGPASB3huYak%3D) | 53272 |  | $0.03 | $0.13 | 98K7786 | Link (http://www.newark.com/webapp/wcs/stores/servlet/Search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)
C7 | 0.1uF | 0.10uF 10% 16V Ceramic Capacitor X7R 0805 | footprints:c_0805 | Murata Electronics North America | GRM219R71C104KA01D | 4 | $0.02 | $0.09 | 245486 |  | $0.14 | $0.56 | 490-1683-1-ND | Link (http://www.digikey.com/scripts/DkSearch/dksus.dll?WT.z_header=search_go&lang=en) | 1347 |  | $0.05 | $0.19 | 2611934 | Link (http://it.farnell.com/murata/grm219r71c104ka01d/cond-mlcc-x7r-0-1uf-16v-0805/dp/2611934) | 43791 |  | $0.12 | $0.48 | 81-GRM40X104K16D | Link (http://www.mouser.com/Search/Refine.aspx?Keyword=GRM219R71C104KA01D%20) | 1302 |  | $0.05 | $0.20 | 96Y9285 | Link (http://www.newark.com/webapp/wcs/stores/servlet/Search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) | 500 |  | $0.02 | $0.09 | 790-0667 | Link (http://it.rs-online.com/web/c/?searchTerm=GRM219R71C104KA01D%20)
R6,R7 | 4,7K | RES SMD 4.7K OHM 5% 1/2W 0805 | footprints:r_0805 | Panasonic Electronic Components | ERJ-P6WJ472V | 8 | $0.44 | $3.52 | 1915 |  | $0.44 | $3.52 | P16962CT-ND | Link (http://www.digikey.com/scripts/DkSearch/dksus.dll?WT.z_header=search_go&lang=en) |  |  |  |  |  |  |  |  | $0.46 | $3.68 | 667-ERJ-P6WJ472V | Link (http://www.mouser.com/Search/Refine.aspx?Keyword=ERJ-P6WJ472V%20)
G1 | LOGO_INTI | Logo INTI | footprints:LOGO_INTI |  |  | 4 | $0.00 | $0.00
CON2 | TP1 | Pad de coneccion para una eventual bateria | footprints:GS2 |  |  | 4 | $0.00 | $0.00
R8 | 4K7 | RES SMD 4.7K OHM 5% 1/2W 0805 | footprints:r_0805 | Panasonic Electronic Components | ERJ-P6WJ472V | 4 | $0.44 | $1.76 | 1915 |  | $0.44 | $1.76 | P16962CT-ND | Link (http://www.digikey.com/scripts/DkSearch/dksus.dll?WT.z_header=search_go&lang=en) |  |  |  |  |  |  |  |  | $0.46 | $1.84 | 667-ERJ-P6WJ472V | Link (http://www.mouser.com/Search/Refine.aspx?Keyword=ERJ-P6WJ472V%20)
D1,D2 | Led | Red 645nm LED Indication - Discrete 1.8V 0805 (2012 Metric) | footprints:LED-0805 | OSRAM Opto Semiconductors Inc. | LH R974-LP-1 | 8 | $0.27 | $2.16 | 141799 |  | $0.33 | $2.64 | 475-1415-1-ND | Link (http://www.digikey.com/scripts/DkSearch/dksus.dll?WT.z_header=search_go&lang=en) |  |  |  |  |  |  | 136542 |  | $0.27 | $2.16 | 720-LHR974-LP-1 | Link (http://www.mouser.com/Search/Refine.aspx?Keyword=LH%20R974-LP-1%20)
C3 | 10uF | 10uF 10% 16V Ceramic Capacitor X5R 0805 | footprints:c_0805 | Murata Electronics North America | GRM21BR61C106KE15K | 4 | $0.06 | $0.24 | 325564 |  | $0.20 | $0.80 | 490-6473-1-ND | Link (http://www.digikey.com/scripts/DkSearch/dksus.dll?WT.z_header=search_go&lang=en) | 3088 |  | $0.07 | $0.27 | 2611940 | Link (http://it.farnell.com/murata/grm21br61c106ke15k/cond-mlcc-x5r-10uf-16v-0805/dp/2611940) |  |  | $0.19 | $0.76 | 81-GRM21BR61C106KE5K | Link (http://www.mouser.com/Search/Refine.aspx?Keyword=GRM21BR61C106KE15K%20) | 14040 |  | $0.13 | $0.52 | 96Y9274 | Link (http://www.newark.com/webapp/wcs/stores/servlet/Search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) | 1700 |  | $0.06 | $0.24 | 820-2762 | Link (http://it.rs-online.com/web/c/?searchTerm=GRM21BR61C106KE15K%20)
R5 | 10K | RES SMD 10K OHM 5% 1/4W 0805 | footprints:r_0805 | Stackpole Electronics Inc. | RPC0805JT10K0 | 4 | $0.13 | $0.53 | 6983 |  | $0.20 | $0.80 | RPC0805JT10K0CT-ND | Link (http://www.digikey.com/product-detail/en/stackpole-electronics-inc/RPC0805JT10K0/RPC0805JT10K0CT-ND/3043921) |  |  |  |  |  |  |  |  |  |  |  |  | 1940 |  | $0.13 | $0.53 | 63W0028 | Link (http://www.newark.com/webapp/wcs/stores/servlet/Search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)

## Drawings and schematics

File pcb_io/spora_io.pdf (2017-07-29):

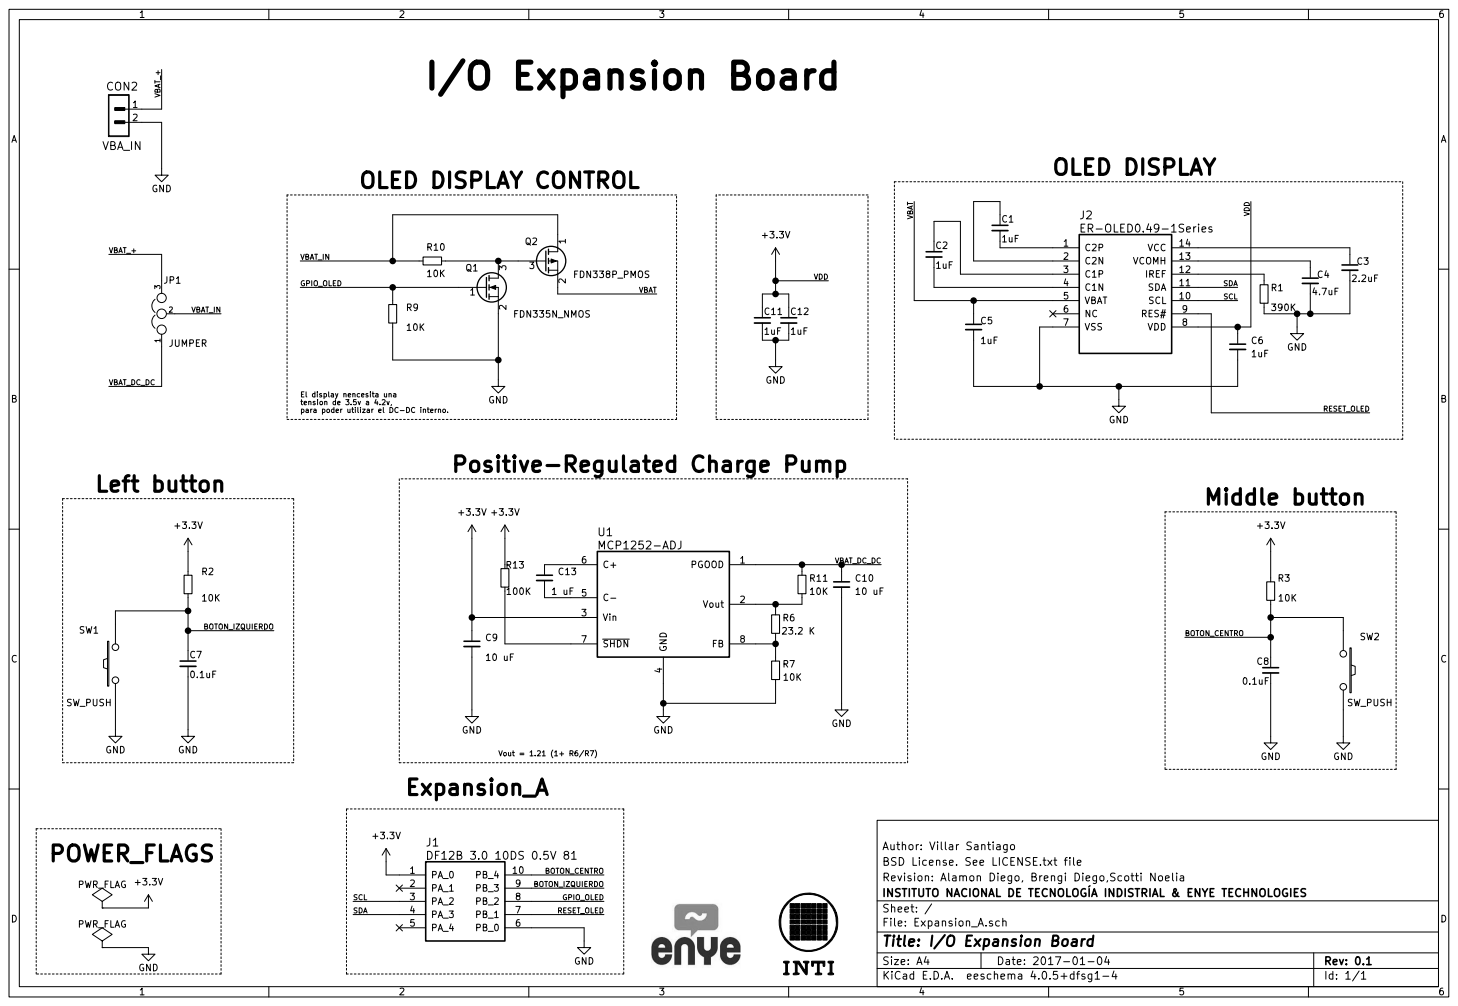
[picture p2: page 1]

tension de 3.5v a 4.2v, para poder utilizar el DC-DC interno. BOTON_IZQUIERDO

El display nencesita una

Vout = 1.21 (1+ R6/R7) Positive-Regulated Charge Pump

Revision: Alamon Diego, Brengi Diego,Scotti Noelia BSD License. See LICENSE.txt file Author: Villar Santiago PWR_FLAG

INSTITUTO NACIONAL DE TECNOLOGÍA INDISTRIAL & ENYE TECHNOLOGIES
File: Expansion_A.sch Sheet: /
Id: 1/1 Title: I/O Expansion Board

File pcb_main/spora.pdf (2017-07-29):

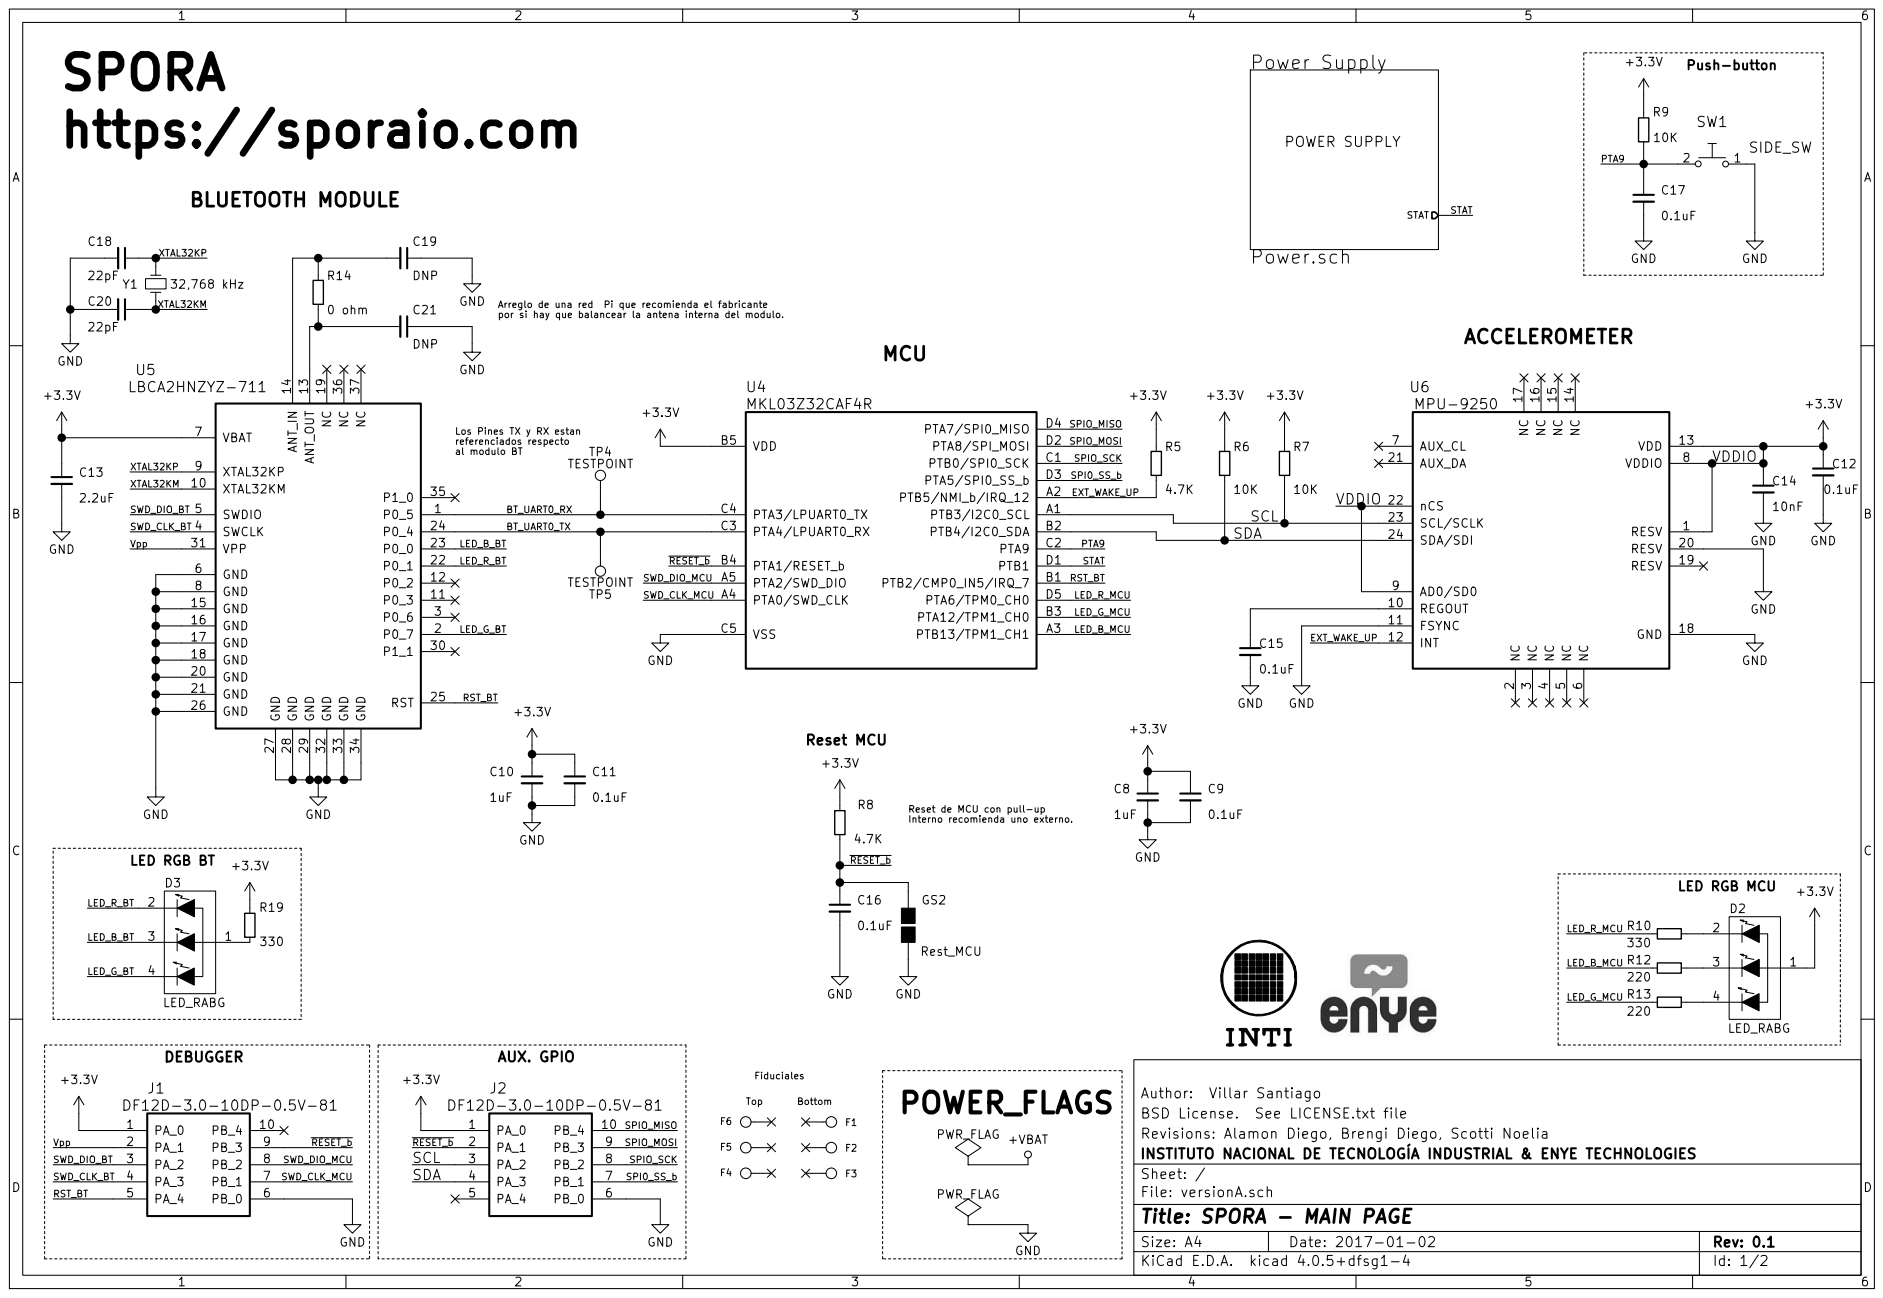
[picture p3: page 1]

Los Pines TX y RX estan referenciados respecto

6 AUX_CL 7 VDDIO 8 AD0/SD0 9 REGOUT 10 RESV 20 FSYNC 11 AUX_DA 21

Reset de MCU con pull-up

Revisions: Alamon Diego, Brengi Diego, Scotti Noelia BSD License. See LICENSE.txt file Author: Villar Santiago PWR_FLAG

INSTITUTO NACIONAL DE TECNOLOGÍA INDUSTRIAL & ENYE TECHNOLOGIES
File: versionA.sch Sheet: /
Id: 1/2 Title: SPORA - MAIN PAGE

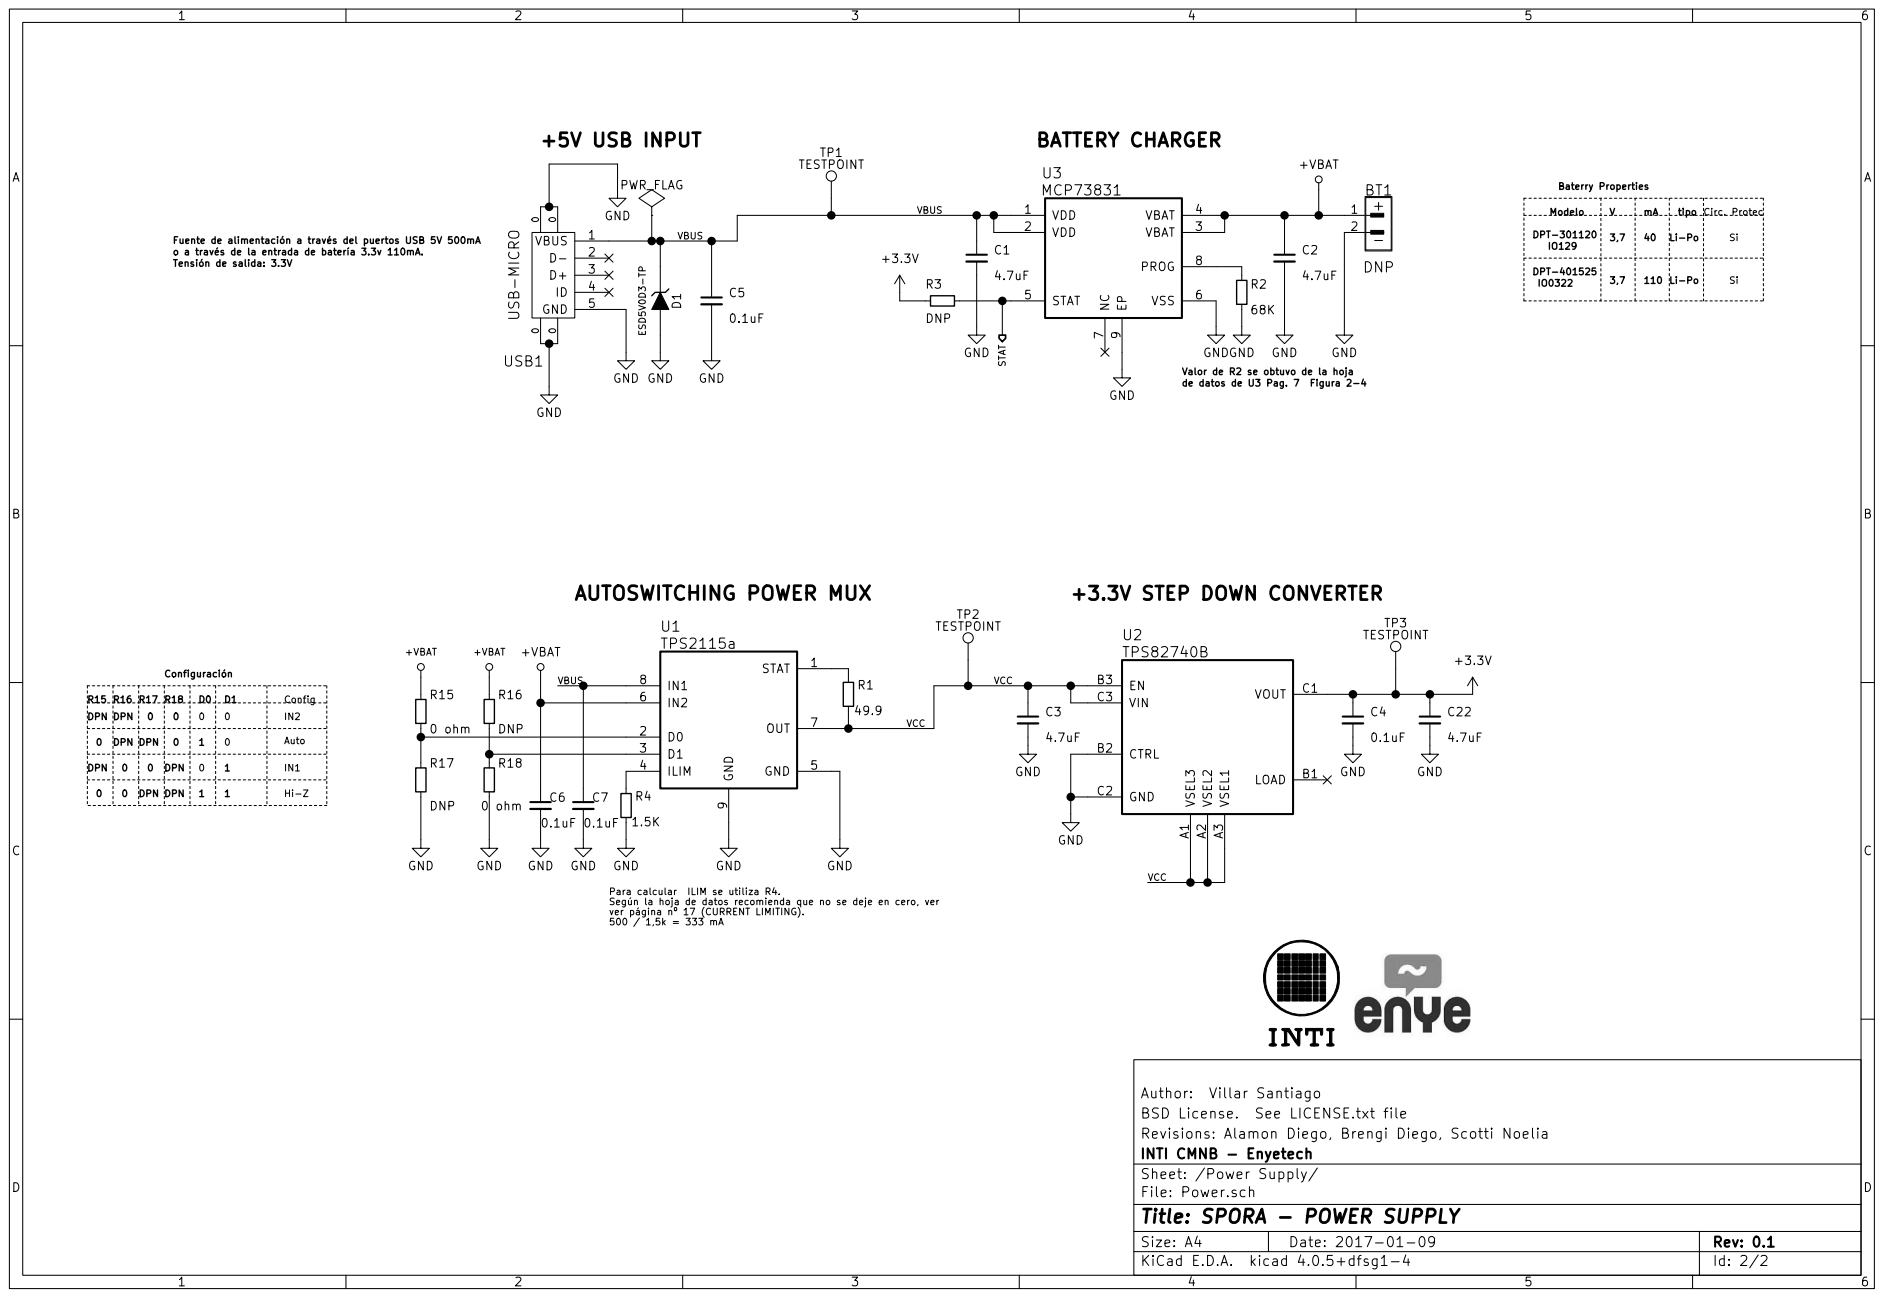
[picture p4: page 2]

Circ. Protec Si Si R15

Fuente de alimentación a través del puertos USB 5V 500mA

VCC AUTOSWITCHING POWER MUX

0 | DPN | 0 DPN | 0 | 1 0 1 | 1 DPN 0 0 | IN2 Auto

Revisions: Alamon Diego, Brengi Diego, Scotti Noelia BSD License. See LICENSE.txt file Author: Villar Santiago GND

INTI CMNB - Enyetech
File: Power.sch Sheet: /Power Supply/
Id: 2/2 Title: SPORA - POWER SUPPLY

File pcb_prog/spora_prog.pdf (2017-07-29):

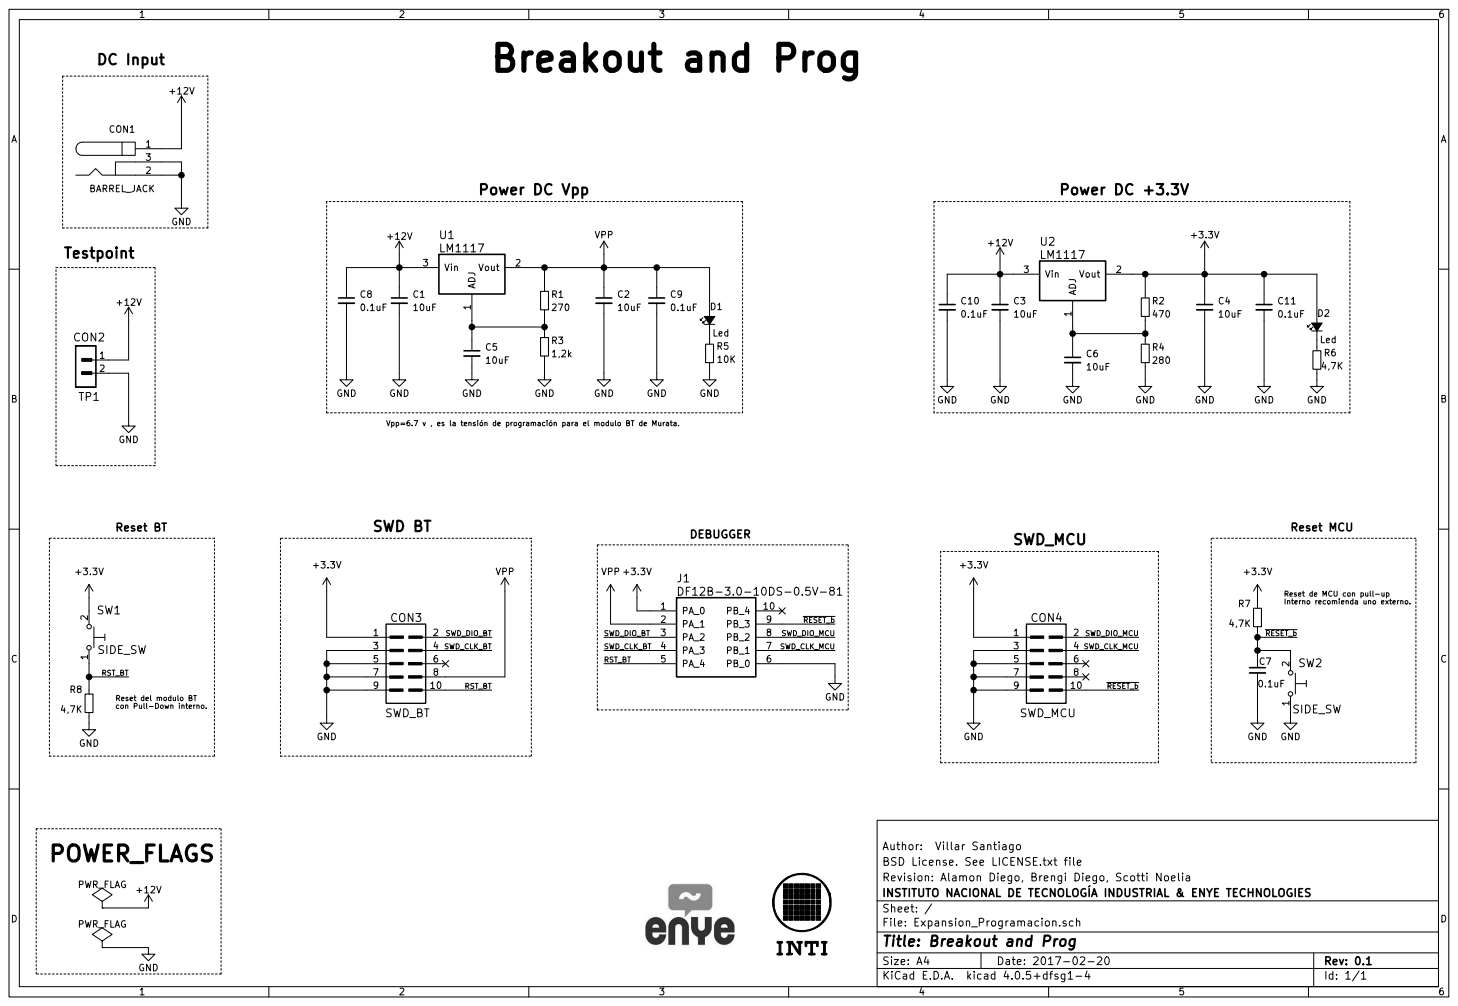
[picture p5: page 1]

3 CON1 BARREL_JACK

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

INSTITUTO NACIONAL DE TECNOLOGÍA INDUSTRIAL & ENYE TECHNOLOGIES
File: Expansion_Programacion.sch Sheet: /
Id: 1/1 Title: Breakout and Prog

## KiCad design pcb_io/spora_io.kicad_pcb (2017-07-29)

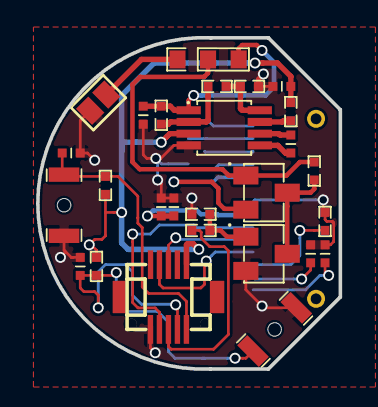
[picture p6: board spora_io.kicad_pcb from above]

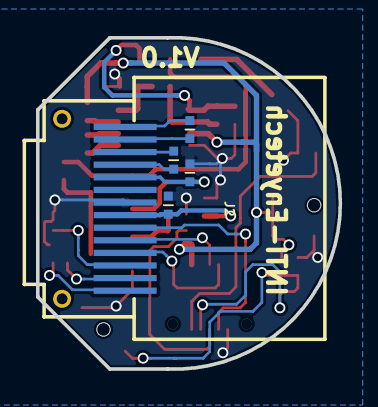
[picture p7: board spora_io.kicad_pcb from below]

Board: 2 copper layers, 16.8 x 18.4 mm, 32 parts (5 on the bottom side), 27 nets.

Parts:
C1, C2, C5, C6, C11, C12: 1uF; c_0402
C3: 2.2uF; c_0402
C4: 4.7uF; c_0402
C7, C8: 0.1uF; c_0402
C9, C10: 10 uF; c_0402
C13: 1 uF; c_0402
CON2: VBA_IN; GS2
J1: DF12B 3.0 10DS 0.5V 81; df12(3.0)-10ds-0.5v
J2: ER-OLED0.49-1Series; ER-OLED0.49-1_B
JP1: JUMPER; JUMPER3_0603
Q1: FDN335N_NMOS; SSOT-3
Q2: FDN338P_PMOS; SSOT-3
R1: 390K; r_0402
R2, R3, R7, R9, R10, R11: 10K; r_0402
R6: 23.2 K; r_0402
R12: 0 ohm; r_0402
R13: 100K; r_0402
SW1, SW2: SW_PUSH; B3U_3000PB
U1: MCP1252-ADJ; MSOP-8

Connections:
+3V3: C9.1, J1.1, R2.1, R3.1, R13.1, U1.3
/BOTON_CENTRO: C8.1, J1.10, R3.2, SW2.2
/BOTON_IZQUIERDO: C7.1, J1.9, R2.2, SW1.2
/GPIO_OLED: J1.8, R12.1
/RESET_OLED: J1.7, J2.9
/SCL: J1.3, J2.10
/SDA: J1.4, J2.11
/VBAT: C5.1, J2.5, Q2.2
/VBAT_+: CON2.1, JP1.3
/VBAT_DC_DC: C10.1, JP1.1, R11.1, U1.1
/VBAT_IN: JP1.2, Q2.1, R10.1
/VDD: C6.1, C11.1, C12.1, J2.8
GND: C3.2, C4.2, C5.2, C6.2, C7.2, C8.2, C9.2, C10.2, C11.2, C12.2, CON2.2, J1.6, J2.7, Q1.2, R1.2, R7.2, R9.2, SW1.1, SW2.1, U1.4
unnamed: C1.1, J2.2
unnamed: C1.2, J2.1
unnamed: C2.1, J2.3
unnamed: C2.2, J2.4
unnamed: C3.1, J2.14
unnamed: C4.1, J2.13
unnamed: C13.1, U1.6
unnamed: C13.2, U1.5
unnamed: J2.12, R1.1
unnamed: Q1.1, R9.1, R12.2
unnamed: Q1.3, Q2.3, R10.2
unnamed: R6.2, R7.1, U1.8
unnamed: R6.1, R11.2, U1.2
unnamed: R13.2, U1.7

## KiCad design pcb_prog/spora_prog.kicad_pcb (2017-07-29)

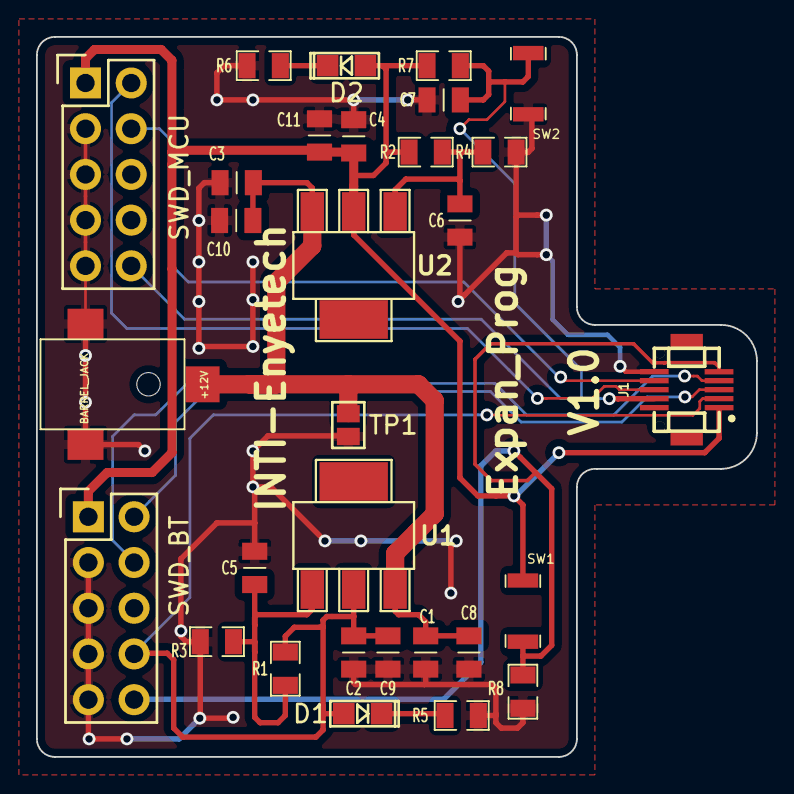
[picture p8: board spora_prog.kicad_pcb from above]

Board: 2 copper layers, 40.0 x 40.0 mm, 30 parts (0 on the bottom side), 14 nets.

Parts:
+12V: BARREL_JACK; Pj-38-smt
C1, C2, C3, C4, C5, C6: 10uF; c_0805
C7, C8, C9, C10, C11: 0.1uF; c_0805
D1, D2: Led; LED-0805
J1: DF12B-3.0-10DS-0.5V-81; df12(3.0)-10ds-0.5v
R1: 270; r_0805
R2: 470; r_0805
R3: 1,2k; r_0805
R4: 280; r_0805
R5: 10K; r_0805
R6, R7: 4,7K; r_0805
R8: 4K7; r_0805
SW1, SW2: SIDE_SW; B3U_1000PB
SWD_BT: SWD_BT; Pin_Header_Straight_2x05
SWD_MCU: SWD_MCU; Pin_Header_Straight_2x05
TP1: TP1; GS2
U1, U2: LM1117; sot223

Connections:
+3V3: C4.1, C11.1, D2.2, J1.1, R2.1, R7.2, SW1.2, SWD_BT.1, SWD_MCU.1, U2.2
+12V: +12V.1, C1.1, C3.1, C8.1, C10.1, TP1.1, U1.3, U2.3
/RST_BT: J1.5, R8.2, SW1.1, SWD_BT.10
/SWD_CLK_BT: J1.4, SWD_BT.4
/SWD_CLK_MCU: J1.7, SWD_MCU.4
/SWD_DIO_BT: J1.3, SWD_BT.2
/SWD_DIO_MCU: J1.8, SWD_MCU.2
/~RESET_b: C7.1, J1.9, R7.1, SW2.2, SWD_MCU.10
GND: +12V.2, +12V.3, C1.2, C2.2, C3.2, C4.2, C5.2, C6.2, C7.2, C8.2, C9.2, C10.2, C11.2, J1.6, R3.2, R4.2, R5.1, R6.1, R8.1, SW2.1, SWD_BT.3, SWD_BT.5, SWD_BT.7, SWD_BT.9, SWD_MCU.3, SWD_MCU.5, SWD_MCU.7, SWD_MCU.9, TP1.2
unnamed: C5.1, R1.2, R3.1, U1.1
unnamed: C6.1, R2.2, R4.1, U2.1
unnamed: D1.1, R5.2
unnamed: D2.1, R6.2
VPP: C2.1, C9.1, D1.2, J1.2, R1.1, SWD_BT.8, U1.2

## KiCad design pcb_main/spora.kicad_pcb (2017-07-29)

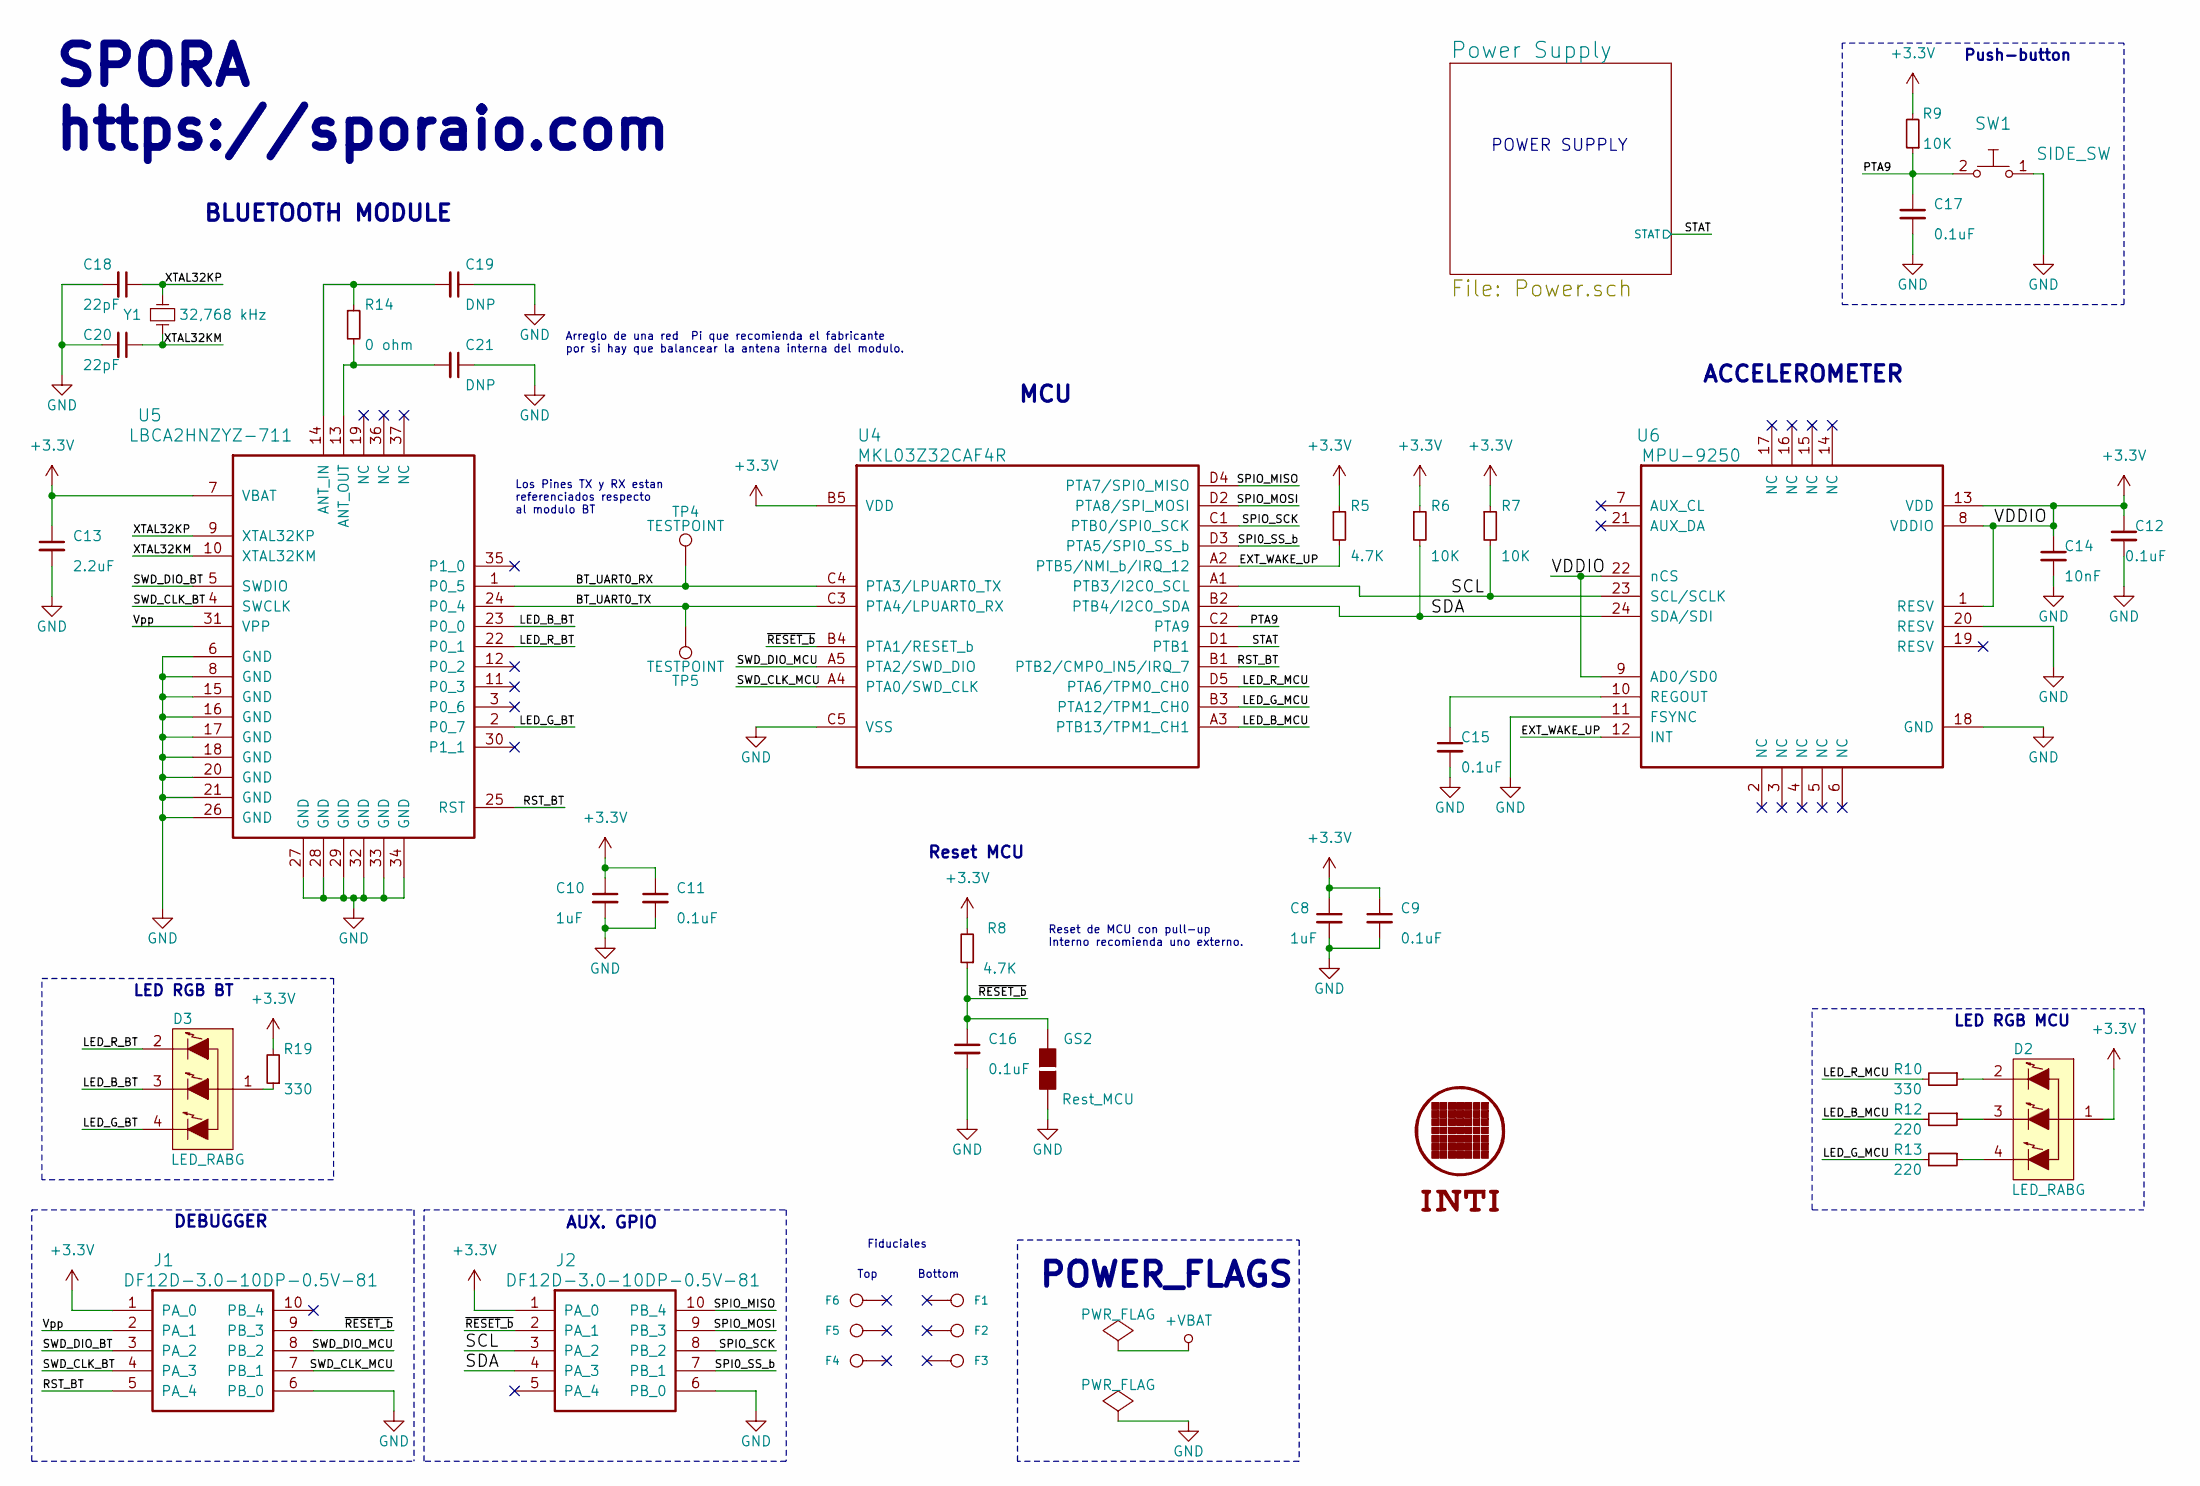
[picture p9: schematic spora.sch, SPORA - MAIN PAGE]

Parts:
C8, C10: 1uF; c_0201; digikey# 1276-6816-1-ND
C9, C11, C12, C15, C16, C17: 0.1uF; c_0201; digikey# 490-5405-1-ND
C13: 2.2uF; c_0201; digikey# 490-13224-1-ND
C14: 10nF; c_0201; digikey# 490-3166-1-ND
C18, C20: 22pF; c_0402; digikey# 732-7427-1-ND
C19, C21: DNP; c_0402
D2, D3: LED_RABG; SML-LX0404SIUPGUSB; digikey# 67-2125-1-ND
F1, F2, F3, F4, F5, F6: CONN_1; FIDUCIAL_65MIL
G1: LOGO_INTI
GS2: Rest_MCU; GS2
J1, J2: DF12D-3.0-10DP-0.5V-81; df12(3.0)-10dp-0.5v; digikey# H11736CT-ND
R5, R8: 4.7K; r_0201; digikey# 311-4.7KNCT-ND
R6, R7, R9: 10K; r_0201; digikey# 311-10KNCT-ND
R10, R19: 330; r_0201; digikey# 311-330NCT-ND
R12, R13: 220; r_0201; digikey# 311-220NCT-ND
R14: 0 ohm; r_0402; digikey# 311-0.0JRTR-ND
SW1: SIDE_SW; B3U_3000PB; digikey# SW1256DKR-ND
TP4, TP5: TESTPOINT
U4: MKL03Z32CAF4R; mouser# 841-MKL03Z32CAF4R; digikey# MKL03Z32CAF4RTR-ND
U5: LBCA2HNZYZ-711; LBCA2A2HNZYZ-711; digikey# 490-10561-1-ND
U6: MPU-9250; digikey# 1428-1019-1-ND
Y1: 32,768 kHz; ABS05-32.768KHZ-9-T; digikey# 535-11897-1-ND

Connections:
+3V3: C8.1, C9.1, C10.1, C11.1, C12.1, C13.1, C14.1, D2.1 (COMMON_ANODE), J1.1 (PA_0), J2.1 (PA_0), R5.1, R6.1, R7.1, R8.2, R9.2, R19.2, U4.B5 (VDD), U5.7 (VBAT), U6.1 (RESV), U6.8 (VDDIO), U6.9 (AD0/SD0), U6.13 (VDD), U6.22 (nCS); also elsewhere on the board
/BT_UART0_RX: TP4.1, U4.C4 (PTA3/LPUART0_TX), U5.1 (P0_5)
/BT_UART0_TX: TP5.1, U4.C3 (PTA4/LPUART0_RX), U5.24 (P0_4)
/EXT_WAKE_UP: R5.2, U4.A2 (PTB5/NMI_b/IRQ_12), U6.12 (INT)
/LED_B_BT: D3.3 (GREEN_CATHODE), U5.23 (P0_0)
/LED_B_MCU: R12.2, U4.A3 (PTB13/TPM1_CH1)
/LED_G_BT: D3.4 (BLUE_CATHODE), U5.2 (P0_7)
/LED_G_MCU: R13.2, U4.B3 (PTA12/TPM1_CH0)
/LED_R_BT: D3.2 (RED_CATHODE), U5.22 (P0_1)
/LED_R_MCU: R10.2, U4.D5 (PTA6/TPM0_CH0)
/PTA9: C17.1, R9.1, SW1.2, U4.C2 (PTA9)
/Power Supply/STAT: U4.D1 (PTB1); also elsewhere on the board
/RST_BT: J1.5 (PA_4), U4.B1 (PTB2/CMP0_IN5/IRQ_7), U5.25 (RST)
/SCL: J2.3 (PA_2), R7.2, U4.A1 (PTB3/I2C0_SCL), U6.23 (SCL/SCLK)
/SDA: J2.4 (PA_3), R6.2, U4.B2 (PTB4/I2C0_SDA), U6.24 (SDA/SDI)
/SPI0_SS_b: J2.7 (PB_1), U4.D3 (PTA5/SPI0_SS_b)
/SPIO_MISO: J2.10 (PB_4), U4.D4 (PTA7/SPI0_MISO)
/SPIO_MOSI: J2.9 (PB_3), U4.D2 (PTA8/SPI_MOSI)
/SPIO_SCK: J2.8 (PB_2), U4.C1 (PTB0/SPI0_SCK)
/SWD_CLK_BT: J1.4 (PA_3), U5.4 (SWCLK)
/SWD_CLK_MCU: J1.7 (PB_1), U4.A4 (PTA0/SWD_CLK)
/SWD_DIO_BT: J1.3 (PA_2), U5.5 (SWDIO)
/SWD_DIO_MCU: J1.8 (PB_2), U4.A5 (PTA2/SWD_DIO)
/Vpp: J1.2 (PA_1), U5.31 (VPP)
/XTAL32KM: C20.1, U5.10 (XTAL32KM), Y1.2
/XTAL32KP: C18.1, U5.9 (XTAL32KP), Y1.1
/~RESET_b: C16.1, GS2.1 (G1), J1.9 (PB_3), J2.2 (PA_1), R8.1, U4.B4 (PTA1/RESET_b)
GND: C8.2, C9.2, C10.2, C11.2, C12.2, C13.2, C14.2, C15.2, C16.2, C17.2, C18.2, C19.1, C20.2, C21.1, GS2.2 (G2), J1.6 (PB_0), J2.6 (PB_0), SW1.1, U4.C5 (VSS), U5.6 (GND), U5.8 (GND), U5.15 (GND), U5.16 (GND), U5.17 (GND), U5.18 (GND), U5.20 (GND), U5.21 (GND), U5.26 (GND), U5.27 (GND), U5.28 (GND), U5.29 (GND), U5.32 (GND), U5.33 (GND), U5.34 (GND), U6.11 (FSYNC), U6.18 (GND), U6.20 (RESV); also elsewhere on the board
unnamed: C15.1, U6.10 (REGOUT)
unnamed: C19.2, R14.1, U5.14 (ANT_IN)
unnamed: C21.2, R14.2, U5.13 (ANT_OUT)
unnamed: D2.2 (RED_CATHODE), R10.1
unnamed: D2.3 (GREEN_CATHODE), R12.1
unnamed: D2.4 (BLUE_CATHODE), R13.1
unnamed: D3.1 (COMMON_ANODE), R19.1

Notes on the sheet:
POWER_FLAGS
AUX. GPIO
Reset MCU
LED RGB MCU
Push-button
DEBUGGER
Los Pines TX y RX estan referenciados respecto al modulo BT
MCU
ACCELEROMETER
BLUETOOTH MODULE
Reset de MCU con pull-up Interno recomienda uno externo.
Arreglo de una red Pi que recomienda el fabricante por si hay que balancear la antena interna del modulo.
POWER SUPPLY
SPORA https://sporaio.com
LED RGB BT
Fiduciales
Top
Bottom

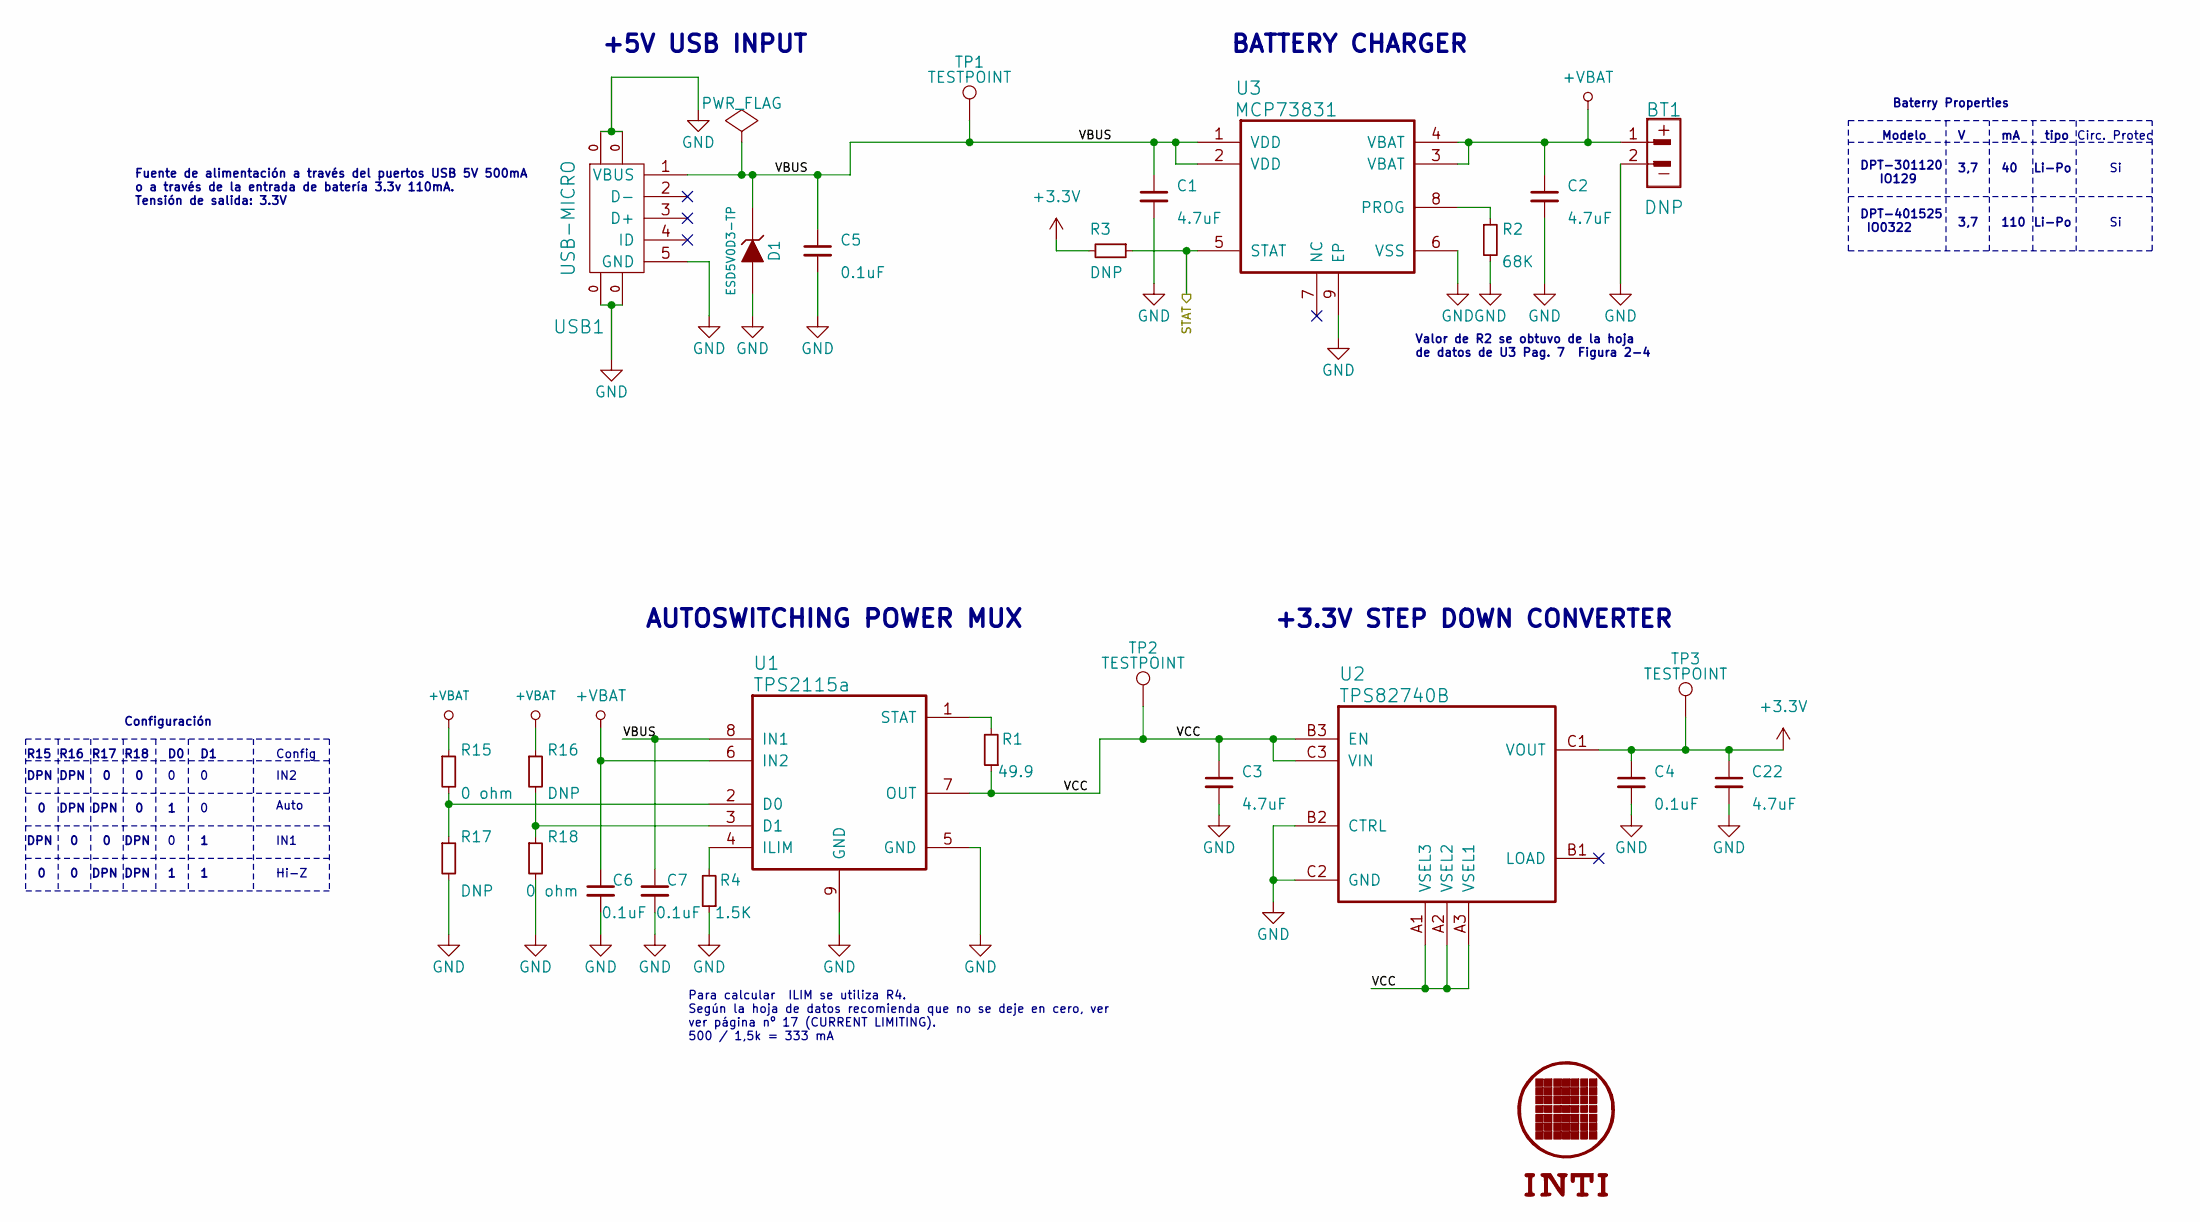
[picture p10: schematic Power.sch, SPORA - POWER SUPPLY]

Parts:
BT1: DNP; BAT_CON
C1, C2, C3, C22: 4.7uF; c_0201; digikey# 490-13230-1-ND
C4, C5, C6, C7: 0.1uF; c_0201; digikey# 490-5405-1-ND
D1: ESD5V0D3-TP; SOD-323; digikey# ESD5V0D3-TPMSCT-ND
G2: LOGO_INTI
R1: 49.9; r_0201; digikey# P49.9ABCT-ND
R2: 68K; r_0201; digikey# P68.0KABCT-ND
R3: DNP; r_0201; digikey# 311-470NCT-ND
R4: 1.5K; r_0201; digikey# 311-1.5KNCT-ND
R15, R18: 0 ohm; r_0402; digikey# 311-0.0JRCT-ND
R16, R17: DNP; r_0402
TP1, TP2, TP3: TESTPOINT
U1: TPS2115a; TPS2115A; digikey# 296-23394-1-ND
U2: TPS82740B; digikey# 296-37973-1-ND
U3: MCP73831; MCP73821; digikey# MCP73831-2ACI/MC-ND
USB1: USB-MICRO; conn_usb_B_micro_smd; digikey# H125279CT-ND

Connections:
+3V3: C4.1, C22.1, R3.2, TP3.1, U2.C1 (VOUT); also elsewhere on the board
+VBAT: BT1.1, C2.1, C6.1, R15.1, R16.1, U1.6 (IN2), U3.3 (VBAT), U3.4 (VBAT)
/Power Supply/STAT: R3.1, U3.5 (STAT); also elsewhere on the board
/Power Supply/VBUS: C1.1, C5.1, C7.1, D1.1 (K), TP1.1, U1.8 (IN1), U3.1 (VDD), U3.2 (VDD), USB1.1 (VBUS)
/Power Supply/VCC: C3.1, R1.1, TP2.1, U1.7 (OUT), U2.A1 (VSEL3), U2.A2 (VSEL2), U2.A3 (VSEL1), U2.B3 (EN), U2.C3 (VIN)
GND: BT1.2, C1.2, C2.2, C3.2, C4.2, C5.2, C6.2, C7.2, C22.2, D1.2 (A), R2.2, R4.1, R17.2, R18.2, U1.5 (GND), U1.9 (GND), U2.B2 (CTRL), U2.C2 (GND), U3.6 (VSS), U3.9 (EP), USB1.0, USB1.5 (GND); also elsewhere on the board
unnamed: R1.2, U1.1 (STAT)
unnamed: R2.1, U3.8 (PROG)
unnamed: R4.2, U1.4 (ILIM)
unnamed: R15.2, R17.1, U1.2 (D0)
unnamed: R16.2, R18.1, U1.3 (D1)

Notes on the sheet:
+3.3V STEP DOWN CONVERTER
AUTOSWITCHING POWER MUX
BATTERY CHARGER
+5V USB INPUT
Valor de R2 se obtuvo de la hoja de datos de U3 Pag. 7 Figura 2-4
Baterry Properties
Modelo
DPT-301120 IO129
DPT-401525 IO0322
3,7
110
tipo
Li-Po
Fuente de alimentación a través del puertos USB 5V 500mA o a través de la entrada de batería 3.3v 110mA. Tensión de salida: 3.3V
Para calcular ILIM se utiliza R4. Según la hoja de datos recomienda que no se deje en cero, ver ver página nº 17 (CURRENT LIMITING). 500 / 1,5k = 333 mA
Circ. Protec
Configuración
R15
R16
DPN
Config
R17
R18
Auto
IN2
IN1
Hi-Z

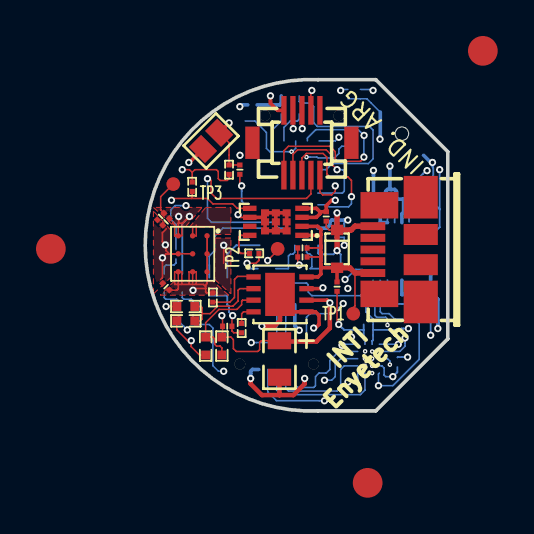
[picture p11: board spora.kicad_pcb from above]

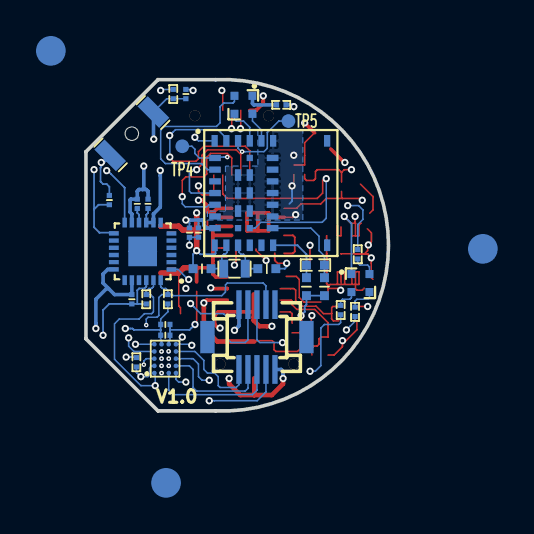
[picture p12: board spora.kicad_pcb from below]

Board: 6 copper layers, 16.8 x 18.4 mm, 67 parts (35 on the bottom side), 43 nets.
